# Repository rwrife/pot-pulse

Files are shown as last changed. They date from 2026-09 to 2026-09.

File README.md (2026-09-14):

# Pot Pulse

USB-powered ESP32-C3 plant-shelf monitor for home growers to track soil moisture, light, and microclimate trends in a local dashboard without cloud accounts or automatic watering.

## Motivation
Houseplant care is mostly guesswork between watering days. People often overwater because they cannot see trend data (light, moisture, humidity) across multiple pots in one place.

## Target users
- Home plant hobbyists with 1–20 potted indoor plants
- Small office/shared-space plant caretakers
- Makers who want a safe, low-voltage, locally controlled monitoring tool

## Concrete use cases
1. Compare morning/evening light exposure per shelf position.
2. Track soil moisture drop rate after watering to tune intervals.
3. Spot dry microclimates near windows/vents before plants decline.
4. Export a local history snapshot for seasonal care adjustments.

## Intended end-to-end workflow
1. Assemble device (SELV USB only) and connect sensors for each monitored pot zone.
2. Join device to local network (or direct USB setup mode).
3. Name shelves/zones in the companion app.
4. Calibrate moisture probes with dry/wet reference points.
5. Review live status + trend charts; set local reminder thresholds.
6. Export CSV/JSON snapshots for personal records.

## MVP features
- ESP32-C3 firmware with periodic sampling (moisture, light, temp/humidity)
- Local-first companion web app (mobile + desktop browsers)
- Per-zone calibration profiles and health-state bands (informational only)
- On-device ring buffer with timestamped readings
- Local network API for status/history/export
- USB recovery/provisioning flow
- Versioned backup/restore of settings and zone metadata

## Non-goals (MVP)
- Automatic watering, relays, or pumps
- Any mains-voltage control path
- Cloud account requirement or remote telemetry service
- Plant diagnosis/treatment claims
- Outdoor/weatherproof deployment

## Privacy, permissions, and data ownership
- Local-first by default: data stored on device and exported by user action.
- No required cloud service.
- Companion app only requests local-network/browser storage permissions needed for setup, caching, and export.
- User can delete local history and reset device from settings.

## Safety limits
- Prototype scope is **SELV USB power only (5V)**.
- Monitoring only; no high-power actuators.
- Not a life-safety, agricultural compliance, or medical system.

## Source tree and artifact policy
Hardware implementation is delivered as editable KiCad source files (not image-only schematics):

- `hardware/kicad/pot-pulse.kicad_pro`
- `hardware/kicad/pot-pulse.kicad_sch`
- `hardware/kicad/pot-pulse.kicad_pcb`

Final BOM source of truth will live in KiCad schematic symbol properties and be exported to tracked `bom/bom.csv`.

## Current status
- ✅ Repository scaffold and execution backlog created
- ✅ MVP architecture, interface ownership, non-goals, and risk baseline documented in [`docs/architecture.md`](docs/architecture.md)
- ✅ Datasheet-backed critical component selection documented in [`hardware/component-selection.md`](hardware/component-selection.md)
- ✅ Editable KiCad project, DRC/ERC evidence, and pad-net cross-check tooling under [`hardware/kicad/`](hardware/kicad/)
- ✅ Firmware MVP with repeatable native tests and ESP32-C3 builds under [`firmware/`](firmware/)
- ✅ Companion app MVP with repeatable typecheck/test/build under [`app/`](app/)
- ✅ Integration bring-up + assembly docs, evidence matrix, and fabrication preview bundle under [`docs/`](docs/)
- 🚧 Production-ready fabrication release still blocked by open PCB unconnected items (see `docs/evidence/2026-09-14/drc.json`)

## Milestones
1. Architecture and risk baseline
2. Datasheet-backed component selection
3. KiCad schematic and ERC
4. Schematic-source BOM and non-schematic procurement tracking
5. PCB layout and DRC
6. Firmware MVP with repeatable build/tests
7. Companion app MVP with local export
8. Integration docs and fabrication-ready release package

See [`PLAN.md`](PLAN.md) for the authoritative issue dependency graph and exit gates.

## Integration handoff docs

- Bring-up procedure: [`docs/bring-up.md`](docs/bring-up.md)
- Assembly sequence and checks: [`docs/assembly.md`](docs/assembly.md)
- Evidence classification: [`docs/evidence-matrix.md`](docs/evidence-matrix.md)
- Fabrication/release workflow: [`docs/release-artifacts.md`](docs/release-artifacts.md)
- Explicit media placeholders: [`docs/media-placeholders.md`](docs/media-placeholders.md)

## Development quickstart
### Firmware
- Toolchain: PlatformIO (ESP-IDF framework)
- Target: ESP32-C3 dev module + custom carrier pin map

### Companion app
- TypeScript + Vite + local-first PWA behavior
- Connect to device over local HTTP/WebSocket

### Hardware
- KiCad 9 project under `hardware/kicad/`
- BOM exported to `bom/bom.csv`

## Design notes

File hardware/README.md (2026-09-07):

# Hardware Overview (Scaffold)

## System block description
Pot Pulse hardware is a USB-powered sensing platform centered on an ESP32-C3 module. It connects low-voltage sensors for:
- ambient temperature/humidity,
- shelf light level,
- multiple soil-moisture channels.

A planned custom carrier provides protection, connectors, debug access, and mounting points.

## Controller choice
- **Primary controller:** Espressif `ESP32-C3-MINI-1-H4X` module (Wi‑Fi + native USB, 4 MB flash).
- Rationale: enough I/O/peripherals for multi-sensor polling and local API hosting.

The datasheet-backed selections for the first schematic pass are recorded in
[`component-selection.md`](component-selection.md), with machine-readable MPN,
supplier, availability, and lifecycle evidence in
[`component-selection.csv`](component-selection.csv). The CSV is an issue #3
handoff only; once the schematic exists, KiCad symbol properties become the BOM
source of truth.

## Interfaces
- USB-C or USB-micro for power + provisioning/debug
- I2C bus for temp/humidity + light sensors
- Analog inputs (direct or via external ADC/mux) for capacitive moisture channels
- UART/JTAG pads for debug/programming

## Power plan
- SELV **USB 5V only** input.
- Onboard 3.3V regulation for logic and sensors.
- Reverse-polarity/overcurrent protections documented in schematic milestone.

## Enclosure/assembly concept
- Small desktop/shelf enclosure with vent slots.
- Detachable sensor leads to each pot zone.
- Standard standoffs/fasteners for at-home assembly.

## Safety limits
- No mains wiring.
- No pump/relay/high-power load control in MVP.
- Indoor hobby monitoring only.

## Expected KiCad deliverables
Planned editable source files:
- `hardware/kicad/pot-pulse.kicad_pro`
- `hardware/kicad/pot-pulse.kicad_sch`
- `hardware/kicad/pot-pulse.kicad_pcb` (if custom PCB remains in scope)

Expected evidence artifacts (later milestones):
- ERC and DRC outputs
- schematic PDF
- Gerbers/drill files
- BOM export from schematic properties (`bom/bom.csv`)

Current state: critical parts selected and the issue #3 first-pass KiCad schematic is available under [`kicad/`](kicad/). Native ERC reports 0 errors and 0 warnings; PCB/layout and physical validation remain later milestones.

Validate the selection handoff from the repository root:

```sh
python3 scripts/validate_component_selection.py
```

Reproduce and validate the schematic with the commands in [`kicad/README.md`](kicad/README.md).

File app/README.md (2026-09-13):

# Pot Pulse Companion App

Local-first companion app (issue #7): setup, live status + trends, and
user-owned export/backup/restore/delete — no cloud, no accounts. Consumes the
frozen `/api/v1` contract from [`docs/protocol.md`](../docs/protocol.md) as
implemented by firmware issue #6.

## Stack (pinned)

| Component | Version |
|---|---|
| Node.js (CI + local) | 22.x |
| TypeScript | 5.6.3 |
| Vite | 5.4.11 |
| Vitest | 2.1.8 |

Vanilla DOM + TypeScript (no framework) keeps the bundle ~15 kB and the
dependency surface minimal.

## Commands

```sh
cd app
npm ci            # pinned install from package-lock.json
npm run typecheck # tsc --noEmit
npm run test      # vitest run (47 unit tests)
npm run build     # production bundle -> app/dist/
npm run dev       # dev server (point it at a device on the LAN)
```

## How it talks to the device

- `src/api/client.ts` — typed client for every frozen resource:
  status, history, pair/request, calibration, config, export, backup,
  restore, history delete (`?confirm=confirm`), reset
  (`{level:"full-firmware",confirm:"confirm"}`). Sends `X-PotPulse-Token`
  once paired; maps `401/409/422/428` to typed errors; tolerates unknown
  additive fields (protocol forward-compat rule).
- `src/core/validation.ts` — mirrors the firmware's frozen bounds client-side
  (zone name ≤ 32, interval 30 s–15 min, `dry_raw != wet_raw`,
  `0 ≤ dry < wet ≤ 1`, history limit 1–500, `backup_version == 1`).
  The device always re-validates.

## Data ownership

- Device flash is authoritative; browser storage (`src/core/store.ts`) holds
  ONLY the device address, pairing token, and a presentation hint — never
  readings. Corrupt cache falls back to defaults.
- Export (CSV/JSON) and backup download happen only on explicit user action;
  the restore file is parsed + validated before posting, and the device
  applies it atomically-or-not-at-all.
- Two separate destructive controls: **Delete device history** (requires the
  frozen confirmation word; settings/calibration kept) and **Delete local app
  data** (wipes this browser's cache only).

## Accessibility basics (issue #7 AC 4)

- Landmarks + skip link; tablist with `aria-selected` and labelled panels.
- `role="status" aria-live="polite"` announcement line for every action result.
- Every input has a real `<label>`; token field is `type="password"`.
- ≥44 px touch targets, visible focus outlines, dark-mode tokens,
  `clamp()`/rem text that scales, WCAG-AA-matched palette, trend chart has a
  text `aria-label`, destructive actions confirm before firing.

## Evidence boundary (issue #7)

- **Static / automated:** `tsc --noEmit` clean; 47 vitest unit tests against a
  scripted fake of the frozen protocol (auth fail-closed, 409 pairing, 428
  confirmation, CSV escaping, uncalibrated-never-valid rendering);
  production Vite build; GitHub Actions `app` workflow.
- **Not claimed:** no end-to-end run against physical ESP32-C3 hardware and
  no screen-reader manual audit — both are bench/field work owned by issue #8.

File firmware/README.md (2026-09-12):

# Firmware (Pot Pulse sensor node)

ESP32-C3 firmware MVP for the pot-pulse carrier (issue #5 board). Local-first:
HTTP JSON API on the LAN plus USB-serial provisioning/recovery; no cloud.

## Layout

- `src/pp/` — portable core (C++17, no Arduino includes): sensor drivers,
  calibration, bounded history, config/pairing store, JSON renderers.
  Compiled in both targets and unit-tested natively.
- `src/main.cpp` — ESP32 device layer: pin map, WebServer endpoints, USB
  serial console, flash persistence (Preferences + LittleFS).
- `test/test_core/` — Unity tests (native env) with fake I2C/clock/KV HALs.

## Toolchain (pinned, AC 1)

| Component | Version |
|---|---|
| PlatformIO Core | 6.1.18 |
| platform-espressif32 | 6.10.0 |
| Arduino core (framework-arduinoespressif32) | 2.0.17 |
| ArduinoJson | 7.4.2 |
| Unity | 2.6.1 |
| Host compiler | g++ `-std=gnu++17` |

Pins live in `platformio.ini` (`espressif32@6.10.0`, `native@1.2.1`,
`ArduinoJson@7.4.2`). Any bump must re-run both commands below and refresh
this file.

## Repeatable build/test commands

```sh
cd firmware
pio test -e native      # portable-core unit tests (19 cases)
pio run  -e esp32c3     # device firmware binary (ESP32-C3)
```

Verified on 2026-09-12 (issue #6 implementing PR):
- `pio test -e native` → `19 test cases: 19 succeeded`
- `pio run -e esp32c3` → `SUCCESS`, RAM 12.2% (40,100/327,680 B),
  Flash 68.0% (891,772/1,310,720 B)

## Flashing (bench, once hardware is available)

```sh
pio run -t upload --upload-port /dev/ttyACM0
pio device monitor
```

## USB serial console (IF-DBG-01 — recovery without Wi-Fi/cloud)

Native USB CDC at 115200. Commands:
`status` · `pair list` · `pair confirm <pair_id>` · `wifi <ssid> <pass>` ·
`reset wifi` · `reset full-firmware` · `help`

Pairing: the app POSTs `/api/v1/pair/request`, then the user runs
`pair confirm <pair_id>` on this console; the 128-bit token is printed ONLY
on the local serial console (out-of-band confirmation, architecture §7).

## Reset levels (protocol `POST /api/v1/reset`)

- `full-firmware` (requires `confirm:"confirm"` + pairing): erases pairing
  tokens, settings, zone metadata, calibration, retained history. Wi-Fi
  credentials are RETAINED so the device stays reachable on the LAN.
- Serial `reset wifi` erases only network credentials.
- A `factory` level erasing Wi-Fi too is deferred until a bench procedure
  exists (needs physical access anyway).

## Evidence boundary (issue #6)

- **Static / automated:** datasheet-transcribed drivers with citations
  (SHT4x DS v6.4, VEML7700 Rev 1.8 + AN 84323, ADS1115 2024 datasheet);
  19 native unit tests; successful ESP32-C3 compile+link.
- **Not claimed:** no bench run on real silicon/sensors, no RF/network
  integration test, no EMC/thermal/field evidence. End-to-end pairing +
  API behavior on hardware is bench work owned by issue #8.
- The HTTP request-handling paths (WebServer glue) are compile-verified only;
  their JSON payloads and state machines ARE unit-tested at the core level.

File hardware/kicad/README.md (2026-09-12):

# Pot Pulse KiCad project

This directory contains the editable KiCad 9 project for the USB-powered Pot Pulse four-zone sensor node: first-pass schematic (issue #3) and first-pass PCB (issue #5).

## Files

- `pot-pulse.kicad_pro` — KiCad project settings.
- `pot-pulse.kicad_sch` — editable schematic source of truth.
- `pot-pulse.kicad_pcb` — editable first-pass PCB (generated by `build_pcb.py`, routed via FreeRouter, DRC-adjudicated).
- `lib/pot-pulse.kicad_sym` — project symbols whose pin maps were transcribed from the manufacturer documents cited in `../component-selection.md`.
- `lib/pot-pulse.pretty/` — project land patterns (ESP32-C3-MINI-1, VEML7700) transcribed from the datasheets cited in `../component-selection.md`; generated by `generate_footprints.py`.
- `fp-lib-table` / `sym-lib-table` — project library registration so the board opens on any machine with KiCad 9.
- `generate_schematic.py` — reproducible first-capture generator; the generated schematic remains editable in KiCad.
- `validate_schematic.py` — static acceptance checks for required parts, properties, nets, pin mappings, test access, and the native ERC summary.
- `netlist_to_json.py` — exports `reports/pcb-input/{netlist,components}.json` (placement/routing input data derived from the schematic netlist).
- `build_pcb.py` — generates `pot-pulse.kicad_pcb` through the pcbnew API (outline, placement table with courtyard/edge asserts, net classes, RF rule areas, pours, text).
- `generate_footprints.py` — generates the project land patterns from datasheet dimensions.
- `route_driver.py` — Specctra DSN export / SES import driver (import saves immediately before probing).
- `dsn_strip_inner_layers.py` — keeps the autorouter on F.Cu/B.Cu so the inner planes stay solid.
- `rip_up_dangling.py` / `rip_up_zone.py` / `rip_up_congested.py` — stranded-fragment and surgical rip-up helpers between router passes.
- `close_stubs.py` — deterministic final stub closer (collision-capsule tested; `--dry` reports LEFT pairs verbatim).
- `fill_zones.py` — headless "Fill All Zones".
- `silk_hygiene.py` — post-route silkscreen cleanup (hides dense-passive refs, shrinks TP/test refs, enforces 0.15 mm text stroke).
- `reload_probe.py` / `check_placement_vs_table.py` / `board_inventory.py` / `list_plane_tracks.py` / `lane_blockers.py` — verification probes (reload integrity, placement-vs-table drift, copper inventory, residual-gap diagnosis).
- `reports/erc.rpt` — native KiCad 9 electrical-rules report.
- `reports/schematic-analysis.txt` — supplemental static analyzer output.
- `reports/pot-pulse.net` — netlist export feeding `netlist_to_json.py`.
- `reports/drc-placement.json` — placement-stage native DRC (pre-routing).
- `reports/routing/` — per-pass DSN/SES/DRC evidence; each `passN-drc.json` is the `kicad-cli` truth for that pass.
- `reports/drc-final.json` — committed final DRC state for `pot-pulse.kicad_pcb`.

Layout intent, keepout strategy, grounding approach, assembly/testability notes, and documented first-pass gaps: `../pcb-design-notes.md`.

## Reproduce and verify

The host needs KiCad 9 symbol libraries and Python 3.11+:

```sh
python3 -m venv /tmp/pot-pulse-kicad-venv
/tmp/pot-pulse-kicad-venv/bin/pip install -r hardware/kicad/requirements.txt
KICAD_SYMBOL_DIR=/usr/share/kicad/symbols \
  /tmp/pot-pulse-kicad-venv/bin/python hardware/kicad/generate_schematic.py
kicad-cli sch erc -o hardware/kicad/reports/erc.rpt hardware/kicad/pot-pulse.kicad_sch
KICAD_SYMBOL_DIR=/usr/share/kicad/symbols \
  /tmp/pot-pulse-kicad-venv/bin/python hardware/kicad/validate_schematic.py \
  --erc hardware/kicad/reports/erc.rpt
```

The PCB steps need the `pcbnew` Python bindings (KiCad container image); all
scripts run inside `hardware/kicad/`:

```sh
kicad-cli sch export netlist pot-pulse.kicad_sch -o reports/pot-pulse.net
python3 netlist_to_json.py
python3 build_pcb.py                       # asserts courtyard/edge placement
python3 reload_probe.py                    # reload integrity + pad-net probe
python3 check_placement_vs_table.py        # board vs build_pcb.py table
python3 route_driver.py export reports/routing/passN.dsn
# host: java -Djava.awt.headless=true -jar freerouting-2.4.1.jar \
#   -de passN-2l.dsn -do passN.ses -mp 12 -gui.enabled=false   (after dsn_strip_inner_layers.py)
python3 route_driver.py import reports/routing/passN.ses
python3 rip_up_dangling.py && python3 fill_zones.py && python3 silk_hygiene.py
python3 close_stubs.py --drc reports/routing/passN-drc.json    # deterministic final stubs
kicad-cli pcb drc --severity-error --severity-warning --format json \
  --output reports/drc-final.json pot-pulse.kicad_pcb
```

The repository's headless `kicad-cli` wrapper runs KiCad 9 in a container. Committed reports are generated from the editable sources, not hand-authored.

## Evidence boundary

Schematic files provide **static schematic and native ERC evidence**. The PCB
provides **static layout + native DRC evidence plus autorouter-derived routing
provenance**. These files do not provide simulation, assembled-board, EMC,
environmental, field, or calibration evidence. RF keepout geometry is
datasheet-derived; measured RF performance is bench evidence not yet claimed.
USB full-speed impedance is not yet stackup-verified (documented gap in
`../pcb-design-notes.md`).

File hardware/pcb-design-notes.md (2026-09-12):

# Pot Pulse first-pass PCB design notes

Editable source: [`kicad/pot-pulse.kicad_pcb`](kicad/pot-pulse.kicad_pcb)
(project [`kicad/pot-pulse.kicad_pro`](kicad/pot-pulse.kicad_pro), KiCad 9).
The board is generated reproducibly through the `pcbnew` Python API —
see `kicad/build_pcb.py` for the placement table and `kicad/README.md` for
the reproduce commands. This document records the layout intent and the
evidence boundaries for issue #5.

## Board outline and mounting strategy

- **Outline:** 70 × 50 mm rectangle on `Edge.Cuts`, 0.05 mm line width.
- **Mounting:** three M3 clearance holes (3.2 mm drill, `MountingHole_3.2mm_M3`
  footprints MK1/MK2/MK3) at (3.6, 3.6), (3.6, 46.4), (63.5, 3.6). The
  top-right corner is intentionally empty: the JST zone-connector bank
  (J2–J5) owns that edge, and `hardware/requirements.md` requires "at least
  two mounting holes." Three holes at non-collinear corners keep the board
  flat in a standoffs enclosure. Hole-to-courtyard clearance is enforced by
  `build_pcb.py check_placement()` and re-checked by native DRC.
- **Layers:** 4-layer intent — F.Cu signal / In1.Cu solid GND plane /
  In2.Cu +3V3 plane / B.Cu signal, 1.6 mm FR-4. If the fab quote pushes
  toward 2 layers, signal routing is already complete on F.Cu/B.Cu only
  (the autorouter was constrained to those layers) and the inner planes
  can be dropped by removing the pour zones; signal integrity then relies
  on the bottom-side return path.

## Connector placement

- **J1 USB-C (power + provisioning):** left edge, mouth centered at
  y = 25 mm, mating face flush with the edge — the cable exits left and
  never crosses the sensor-cable bundle.
- **J2–J5 JST-PH zone connectors:** right edge at x = 66.9 mm, 9.2 mm
  pitch, cables exit rightward away from the antenna band.
- **J6 6-pin debug/programming header:** top edge (55, 47.5), rotated 180°
  so the keyed notch faces outward; sits next to the MCU for short UART/BOOT
  fanout.
- **Sensor/RF separation:** USB entry + input protection + buck sit on the
  top band between J1 and the MCU; the ADS1115 + probe conditioning + zone
  bank live on the right; the ESP32-C3-MINI-1 is rotated 180° so its PCB
  antenna points at the bottom edge.

## Keepout strategy

- **RF keepout (hard rule area, all copper/via/track forbidden):** rectangle
  x 24–46 mm, y < 17.4 mm in front of the U2 antenna end (bottom edge). It
  stops 0.075 mm clear of U2's courtyard so the rule area does not graze the
  module (a grazing rule area flags the footprint as an `items_not_allowed`
  DRC error). This matches the ESP32-C3-MINI-1 datasheet keepout figure;
  actual RF performance still requires bench verification.
- **Edge strategy:** copper edge clearance 0.5 mm design rule; test points
  and mounting holes are placed so no silk or copper violates it.
- The keepouts are committed in the board file as rule-area zones (KiCad
  "rule areas"), so they are DRC-enforced, not just documentation.

## Grounding approach

- **Solid GND plane:** In1.Cu is a single uninterrupted +GND pour with no
  splits; F.Cu carries a second GND pour stitched to the plane through via
  fences along the main signal corridors and under every IC ground pad.
  This is the "explicit grounding approach" for the critical nets: USB
  shield/return, buck input/output loops, and ADC analog returns all have a
  plane directly beneath their signal layer.
- **+3V3:** In2.Cu plane plus an F.Cu pour around the sensor/ADC cluster;
  the Power net class (0.5 mm / 0.7–0.35 vias) carries VBUS → protection →
  buck → +3V3 bulk path.
- **Analog class:** MOISTURE_AIN* / PROBE*_RAW run 0.20 mm / 0.25 mm
  clearance away from the buck switch node and the antenna band; returns
  reference the solid GND plane.

## Critical-net routing record (first pass)

| Net group | Class | Notes |
|---|---|---|
| VBUS, +5V_PROTECTED, SW_NODE, +3V3, GND | Power 0.5 mm | Short buck loop J1→F1/D1→U1→L1→C3/C4; bulk caps adjacent to the IC. |
| USB_DP/DM, USB_CONN_DP/DM | USB 0.15 mm | USB-C staggered 0.5 mm-pitch pads (0.3×1.15 mm) physically cannot pass a 0.2 mm corridor; 0.15 mm is the documented fanout compromise. **Not impedance-controlled on this pass** — see gaps below. |
| I2C (SCL/SDA) | Default 0.2 mm | Shared bus U2→R4/R5 pull-ups→U5/U6→TP5/TP6, single trunk, no stubs >10 mm. |
| MOISTURE_AIN* / PROBE*_RAW | Analog | Filtered (R/C grid) per probe channel to U3 (ESD) and U4 (ADS1115). |
| EN, BOOT, U0RXD/TXD, REG_PG, ADC_ALERT_N | Default | Debug/diagnostic nets to J6 and test points. |

## DRC evidence and remaining known gaps

Native reports (regenerate with the commands in `kicad/README.md` §PCB):

- `kicad/reports/drc-placement.json` — placement-only stage (before routing).
- `kicad/reports/routing/passN-drc.json` — per-router-pass adjudication.
- `kicad/reports/drc-final.json` — final committed state.

Adjudication is always `kicad-cli pcb drc --format json` on the reloaded
board, never the router's own log (the two metrics count different things).

Committed final state (`reports/drc-final.json`): **0 error-class violations
(clearance/shorts/courtyards/keepouts/copper-edge all clean) and 0 warning-
class violations except one dangling via; 5 ratsnest pairs remain unrouted**:

| # | Net | Gap (verbatim DRC pair) |
|---|-----|---|
| 1 | +3V3 | `Pad 3 [/+3V3] of U5` ↔ 1.77 mm F.Cu stub |
| 2 | I2C_SCL | `Pad 2 [/I2C_SCL] of U5` ↔ 3.21 mm F.Cu stub |
| 3 | I2C_SDA | dangling B.Cu via at (52.97, 24.94) ↔ `Pad 1 [/I2C_SDA] of U5` |
| 4 | USB_CONN_DM | `Pad A7 [/USB_CONN_DM] of J1` ↔ 0.88 mm F.Cu stub |
| 5 | VBUS | `Track [/VBUS] on B.Cu` (4.80 mm) ↔ `Track [/VBUS] on B.Cu` |

Root causes are congestion, not missing routes:

- **U5 (SHT4x DFN-4, 0.8 mm pitch, 0.5×0.3 mm pads):** at the 0.2 mm
  design clearance a track physically cannot pass between adjacent pads
  (pad gap 0.5 mm < track+2×clearance = 0.6 mm). The three U5 fanout stubs
  need either a local clearance relaxation (like the USB class) or a small
  pad sweep before the next router pass. Documented as a known limitation
  for pass 2, not hidden.
- **USB-C staggered fanout (USB_CONN_DM A7):** the 0.5 mm staggered row is
  already routed at the 0.15 mm USB-class compromise; the last A7 hop
  collides with the DP stub. Needs a fan-out re-order (B-row first) next pass.
- **VBUS B.Cu gap:** the A9↔A4 bridge is closed (deterministic stub-closer);
  the remaining 4.8 mm gap is between two B.Cu trunks across the USB corner,
  blocked by J1 pads/shield. A Z-detour at 0.2 mm clearance fails the
  capsule collision test (dumped verbatim by `lane_blockers.py`).

`close_stubs.py --dry` against the final DRC reports these pairs verbatim
(`LEFT` lines); `final_pipeline.py` reproduces the exact committed board from
`build_pcb.py` + `reports/routing/t1.ses`.

Documented first-pass gaps (intentional, each with a rationale):

1. **USB full-speed impedance is not controlled** on the 4-layer stackup
   guess (no fab stackup confirmed yet). Acceptable for full-speed USB
   provisioning per the architecture doc; revisit when a fab stackup is
   quoted.
2. **No solder-mask/paste design review against a specific fab** — design
   rules are set to JLCPCB-2-layer-capable minimums (0.2 mm clearance,
   0.2 mm track, 0.3/0.6 vias); fab-specific CAM review is a fabrication
   milestone, not this issue.
3. RF keepout geometry is datasheet-derived; measured antenna performance
   is bench evidence we do not yet claim.

## Assembly and testability notes

- **Probe access:** sixteen 1.5 mm test points (TP1–TP16) in two blocks
  (bottom-left rail/debug cluster: VBUS, +5V_PROTECTED, +3V3, GND, I2C,
  USB_DP/DM, AIN2/AIN3; bottom-right analog/diagnostic row: REG_PG, EN,
  BOOT, ADC_ALERT_N, AIN0/AIN1). All are outside the RF keepout and clear of
  connector mating envelopes. TP references stay visible on silk (identity
  is part of testability); dense passives use F.Fab-only references.
- **Connector orientation checks (assembly-time):** J1 mouth must be flush
  with the left Edge.Cuts line (0.2 mm inset); J2–J5 locking-latch side
  faces the board edge so cables pull outward; J6 notch faces outward for
  ribbon-key alignment. Silkscreen pin-1 marks are present on J2–J6; J1 is
  mechanically keyed.
- **Polarity/orientation-sensitive parts:** D1 (SOD-523) band toward the
  buck input; U7 USBLC6 pin-1 dot toward J1; U1 buck EP with thermal via
  cluster (do not hand-solder without hot-air); F1 fuse 1812; C1/C3/C4
  1206 bulk — all have silk pin-1/orientation marks from footprint graphics.
- **Mounting:** M3 standoffs at MK1–MK3; no components within the 6 mm
  courtyard of any hole.
- **Test sequence hook:** TP1/TP2/TP3/TP4 are 5V/3V3/GND rails — first
  bring-up step is a rail check at these four pads before plugging in the
  zone cables.

## Reproducing the routing evidence

```sh
# from hardware/kicad/ (pcbnew container per kicad/README.md)
python3 netlist_to_json.py            # refresh reports/pcb-input/*.json
python3 build_pcb.py                  # rebuild board from placement table
python3 route_driver.py export reports/routing/passN.dsn
# host: FreeRouter headless (JDK25 + freerouting-2.4.1.jar)
#   java -Djava.awt.headless=true -jar freerouting-2.4.1.jar \
#     -de passN.dsn -do passN.ses -mp 12 -gui.enabled=false
python3 route_driver.py import reports/routing/passN.ses
python3 rip_up_dangling.py            # drop stranded fragments
python3 fill_zones.py                 # refill pours after import
python3 close_stubs.py --drc reports/routing/passN-drc.json   # deterministic final stubs
kicad-cli pcb drc --severity-error --severity-warning --format json \
  --output reports/drc-final.json pot-pulse.kicad_pcb
```

`dsn_strip_inner_layers.py` keeps the router on F.Cu/B.Cu so the inner
planes stay solid; `rip_up_congested.py` is the surgical rip-up used to
clear autorouter dead-ends before a targeted pass.

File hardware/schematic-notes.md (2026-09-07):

# Schematic notes and interface contract

**Revision:** A0 first-pass schematic, 2026-09-07
**Editable source:** [`kicad/pot-pulse.kicad_sch`](kicad/pot-pulse.kicad_sch)

The schematic implements the issue #1 architecture and issue #2 datasheet-backed selections. Manufacturer documents listed in [`component-selection.md`](component-selection.md) are the electrical ground truth. KiCad connectivity and ERC are static evidence, not physical validation.

## Power tree

```text
USB-C J1 VBUS
  -> F1 MF-MSMF050-2 (0.50 A hold / 1.00 A trip)
  -> +5V_PROTECTED
     -> D1 ESD5Z5.0T1G to GND
     -> U1 TPS62162DSGR fixed 3.3 V buck
        -> L1 2.2 uH
        -> +3V3
```

`+3V3` powers the ESP32-C3 module, ADS1115, SHT40, VEML7700, probe connectors, and I2C pull-ups. `VBUS`, `+5V_PROTECTED`, `+3V3`, and `GND` have ERC source declarations and labeled test pads. The 0.50 A PPTC rating and regulator capacity are static ratings only; startup, radio burst droop, ripple, and nuisance-trip behavior remain bench work for issue #8.

TPS62162 connections follow TI's fixed-output guidance: FB and the exposed pad go to GND, VOS senses `+3V3`, SW feeds the selected 2.2 uH inductor, and PG has a 100 kOhm pull-up. The input/output network is 10 uF plus 100 nF at the input and 22 uF at the output.

## Named interfaces

| Interface | Nets | Ownership / use |
|---|---|---|
| USB Type-C sink | `VBUS`, `CC1`, `CC2`, `USB_CONN_DP`, `USB_CONN_DM` | J1 entry; CC1/CC2 each have independent 5.1 kOhm Rd |
| Protected native USB | `USB_DP`, `USB_DM` | U7 USBLC6-2SC6 to ESP32-C3 GPIO19/GPIO18 |
| Regulator status | `REG_PG`, `SW_NODE` | `REG_PG` is testable; `SW_NODE` is local to the buck/inductor loop |
| Shared I2C | `I2C_SDA`, `I2C_SCL` | ESP32 GPIO4/GPIO5; ADS1115 0x48, SHT40 0x44, VEML7700 0x10 |
| ADC ready | `ADC_ALERT_N` | ADS1115 open-drain ALERT/RDY to ESP32 GPIO6 with 10 kOhm pull-up |
| Probe entry | `PROBE1_RAW` ... `PROBE4_RAW` | JST PH pin 3 through TPD4E05U06 boundary protection |
| Filtered moisture | `MOISTURE_AIN0` ... `MOISTURE_AIN3` | 1 kOhm / 100 nF RC outputs to ADS1115 AIN0..AIN3 |
| Reset / boot | `EN`, `BOOT_GPIO9` | EN pull-up/1 uF reset delay; GPIO9 boot strap pull-up and debug access |
| UART fallback | `U0RXD`, `U0TXD` | ESP32-C3 GPIO20/GPIO21 at J6 |

## Connector pinout

### J2–J5 moisture probes

All four connectors use the same orientation:

1. `+3V3`
2. `GND`
3. `PROBEn_RAW`

They target JST `S3B-PH-K-S(LF)(SN)` and the SEN0193 PH2.0-3P cable family. The board silkscreen and assembly guide must repeat this mapping, and issue #5/#8 must check the received cable orientation before power is applied.

### J6 unpopulated debug/program pads

1. `+3V3`
2. `GND`
3. `EN`
4. `BOOT_GPIO9`
5. `U0RXD`
6. `U0TXD`

Native USB is the normal provisioning/recovery path. J6 is a fallback for UART flashing and controlled reset/boot entry.

## Test access

The schematic provides 16 unpopulated test pads:

- rails: `VBUS`, `+5V_PROTECTED`, `+3V3`, `GND`;
- representative bus: `I2C_SDA`, `I2C_SCL`;
- USB: `USB_DP`, `USB_DM`;
- control/status: `REG_PG`, `EN`, `BOOT_GPIO9`, `ADC_ALERT_N`;
- analog: `MOISTURE_AIN0` through `MOISTURE_AIN3`.

Issue #5 owns final probe-pad placement, keepouts, silkscreen labels, and physical accessibility.

## Net naming conventions

- `+<voltage>` denotes a regulated or protected power rail, for example `+3V3` and `+5V_PROTECTED`.
- `VBUS` is the raw USB connector rail before F1.
- `_N` suffix means active-low or open-drain asserted-low behavior.
- `USB_CONN_*` names the connector side of U7; `USB_*` names the protected MCU side.
- `PROBEn_RAW` names an external connector node before the RC filter.
- `MOISTURE_AINn` names a filtered ADS1115 single-ended channel.
- `I2C_*` is the single shared assembled bus; only R4/R5 provide board pull-ups.
- `SW_NODE` is a high-dV/dt local switching node and must not be used elsewhere.
- GPIO function is included where it is an interface contract (`BOOT_GPIO9`, `U0RXD`, `U0TXD`); spare GPIO nets are explicitly named and testable in the source but are not external interfaces.

## Datasheet pin-map checks

The project symbol library records these reviewed mappings:

- ESP32-C3-MINI-1 v2.2 Table 3-1: pad 3=3V3, 8=EN, 18=GPIO4, 19=GPIO5, 20=GPIO6, 23=GPIO9, 26=USB_D-, 27=USB_D+, 30=GPIO20/U0RXD, 31=GPIO21/U0TXD, and all documented GND/NC pads.
- ADS1115 Rev. E Table 4-1: 1=ADDR, 2=ALERT/RDY, 3=GND, 4..7=AIN0..AIN3, 8=VDD, 9=SDA, 10=SCL.
- TPS6216x Rev. E pin functions: 1=PGND, 2=VIN, 3=EN, 4=AGND, 5=FB, 6=VOS, 7=SW, 8=PG, exposed pad=AGND.
- SHT4x v7.3 Figure 18: 1=SDA, 2=SCL, 3=VDD, 4=VSS.
- VEML7700 Rev. 1.8: 1=SCL, 2=VDD, 3=GND, 4=SDA.
- TPD4E05U06 Rev. O Table 4-2: protected channels on 1, 2, 4, 5; GND on 3 and 8; remaining pads NC.

## ERC configuration and intentional limits

The committed native KiCad report must contain zero electrical errors and zero warnings. No electrical violation is waived. Two footprint identifiers (`pot-pulse:ESP32-C3-MINI-1` and `pot-pulse:VEML7700`) intentionally name project land patterns that issue #5 must implement and validate against the manufacturer drawings before PCB placement. That is a PCB/library handoff, not electrical ERC evidence.

## Evidence not yet available

- No PCB layout or DRC evidence exists (issue #5).
- No SPICE simulation was run; this milestone does not claim ripple, transient, filter-settling, or signal-integrity simulation.
- No assembled hardware, voltage/current measurement, USB enumeration, sensor readout, ESD, thermal, environmental, or field test was performed.
- Probe calibration accuracy and dry/wet repeatability remain firmware/bench tasks.

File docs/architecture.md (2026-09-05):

# Pot Pulse MVP Architecture and Risk Baseline

**Status:** Proposed baseline; becomes the accepted MVP baseline when issue #1 is merged.

**Scope:** Issues #2–#8 must conform to this document or update it explicitly in the same pull request.

**Evidence boundary:** This document defines design intent. It is not electrical, simulation, bench, field, or certification evidence.

## 1. Purpose and constraints

Pot Pulse is a local-first, indoor plant-monitoring system. One USB-powered sensor node samples four soil-moisture zones plus device-level illuminance, temperature, and relative humidity. Firmware calibrates and stores readings, then exposes a versioned local API. A browser-based companion app owns setup, visualization, user-initiated export, and local backup/restore workflows.

The MVP is constrained to:

- SELV USB 5 V input and 3.3 V logic/sensors;
- at least four independent capacitive moisture channels;
- one device-level digital ambient sensor and one digital light sensor;
- local operation without a cloud account or cloud relay;
- a normal-mode average-current target of 250 mA or less;
- indoor operation at a nominal 10–35 °C ambient;
- a user-serviceable sensor-node assembly with a target carrier size of 120 mm × 80 mm or less and at least two mounting holes;
- a prototype electronics-plus-enclosure cost target of USD 35–60 and a soft ceiling of USD 75, excluding the host device, tools, shipping, and tax.

This architecture is authoritative for subsystem boundaries, ownership, safety constraints, and non-goals. [`hardware/requirements.md`](../hardware/requirements.md) remains authoritative for measurable hardware acceptance requirements. Any conflict must be resolved by updating both documents in the same pull request; neither silently overrides the other.

Exact components, packages, connector families, and the ADC/multiplexer topology are intentionally deferred to datasheet-backed component selection in issue #2. Those choices may refine this baseline but must preserve its external boundaries and requirements unless the architecture is revised explicitly.

## 2. System context

### 2.1 Context diagram

```text
                              user-owned local environment

  Capacitive probes (×4) ─┐
  Ambient sensor ─────────┼──> [ Pot Pulse sensor node ] <── USB 5 V + setup host
  Light sensor ───────────┘        |        |
                                   |        +── USB serial diagnostics/recovery
                                   |
                                   +── local HTTP / optional WebSocket
                                                |
                                                v
                                      [ Companion web app ]
                                         |             |
                                         v             v
                                  browser cache   CSV/JSON or
                                                  backup files
```

### 2.2 Block narrative

1. **Hardware platform:** accepts only SELV USB 5 V, protects and regulates the supply, connects the ESP32-C3 module to four moisture inputs and shared digital environmental sensors, and exposes programming/debug/test access.
2. **Firmware:** owns hardware initialization, scheduled sampling, quality flags, calibration transforms, bounded on-device history, configuration persistence, pairing authorization, and the versioned device API.
3. **Companion app:** discovers or connects to one device, guides naming and calibration, presents current/history data, manages user-entered metadata and reminders, and performs explicit export, backup, restore, and delete operations through documented APIs.
4. **User-controlled storage:** device flash is authoritative for device configuration, calibration, and bounded readings. Browser storage is a disposable app cache. User-created CSV/JSON and backup files are portable records controlled by the user.
5. **External systems:** the local network and USB host provide transport only. No cloud service is required for setup, normal monitoring, history, or export.

### 2.3 Trust and ownership boundaries

- The **sensor node** is the authority for raw readings, calibration parameters applied to those readings, sensor-health state, sampling cadence, and retained device history.
- The **app** is the authority for presentation state and browser-local cache. It must not silently reinterpret raw values or manufacture missing samples.
- The **user** owns exported data, plant/zone naming, reminder thresholds, and destructive-operation confirmation.
- The **local network is not assumed private enough for configuration writes**. Firmware must require a locally established pairing credential for state-changing API operations. Final authentication mechanics are a firmware/protocol decision, but unauthenticated writes are prohibited.
- Hardware provides electrical connectivity; firmware owns bus transactions. App code must not depend on pin numbers, I2C addresses, ADC channels, or component choices.

## 3. Subsystem responsibilities

### 3.1 Hardware

Hardware owns:

- USB input protection and 5 V-to-3.3 V power integrity;
- ESP32-C3 module, sensor, probe, debug, and test-point connectivity;
- signal conditioning and protection required by selected probes and external connectors;
- four electrically distinct moisture acquisition channels;
- I2C electrical implementation for the ambient and light sensors;
- connector keying/orientation documentation and enclosure mounting constraints.

Hardware does not own calibration policy, threshold meaning, retention policy, UI behavior, or network authorization.

### 3.2 Firmware

Firmware owns:

- deterministic sensor initialization and sample scheduling;
- conversion of hardware observations to typed readings with quality flags;
- dry/wet calibration storage and application per moisture zone;
- timestamps and bounded history retention;
- configuration validation, persistence, reset, and recovery;
- pairing credentials and authorization of state-changing operations;
- the `/api/v1` HTTP contract and optional WebSocket event stream;
- USB serial diagnostics and a recovery path that does not require Wi-Fi or cloud access.

Firmware must preserve raw moisture readings alongside calibrated values so calibration can be audited or replaced.

### 3.3 Companion app

The app owns:

- connection/setup guidance, zone naming, and calibration workflow;
- accessible live status and historical trend presentation;
- local reminder configuration without control of physical actuators;
- explicit CSV/JSON export, backup, restore, and deletion UX; firmware generates and validates canonical device data while the app owns user initiation, transfer, and local file handling;
- validation of user input before sending it to the device;
- clearly distinguishing offline/stale data from current device readings.

The app must consume the versioned protocol and must not directly encode board pinout or sensor-driver assumptions.

## 4. Interface contracts

| ID | Boundary | Producer / owner | Consumer | Inputs | Outputs / contract | Required verification |
|---|---|---|---|---|---|---|
| IF-PWR-01 | USB source → hardware | Hardware | Entire sensor node | SELV USB 5 V only | Protected input and regulated 3.3 V rail; normal-mode average target ≤250 mA | Schematic/ERC review; regulator/protection datasheet checks; bench rail and current measurements |
| IF-MOI-01 | Moisture probes → acquisition hardware | Hardware | Firmware sensor abstraction | Four independent analog probe signals and connector return/reference | Stable per-channel ADC observations plus open/out-of-range detectability where supported | Schematic pinout review; channel-isolation test; dry/wet bench characterization |
| IF-I2C-01 | Ambient/light sensors ↔ MCU | Hardware owns electrical bus; firmware owns transactions | Firmware drivers | 3.3 V I2C, selected addresses, interrupt lines only if documented | Typed temperature °C, relative humidity %RH, illuminance lux, and quality state | Datasheet pin/address validation; bus enumeration and fault-injection tests |
| IF-DBG-01 | USB/debug host ↔ node | Firmware owns command semantics; hardware owns physical path | Setup/diagnostic operator | USB serial or selected native USB path | Provisioning, diagnostics, and recovery/reset without cloud dependency | Repeatable flashing/recovery procedure and failed-Wi-Fi recovery test |
| IF-STO-01 | Firmware services ↔ device flash | Firmware | Firmware API/sampling services | Versioned settings, calibration, zone metadata, bounded readings | Atomic validated records; recoverable defaults after corrupt/incompatible data | Unit tests for migration, bounds, interrupted write, reset, and retention |
| IF-API-01 | Device ↔ companion app | Firmware owns `/api/v1`; app owns client use | Companion app | Pairing credential for writes; bounded query parameters | JSON status/history/config/calibration/export/backup/restore/delete/reset resources defined in [`docs/protocol.md`](protocol.md) | Shared schema/fixture tests plus local integration tests |
| IF-LIVE-01 | Device → companion app | Firmware | Companion app | Optional authenticated WebSocket subscription | Best-effort live events using the same reading schema as HTTP; HTTP remains functional fallback | Disconnect/reconnect, duplicate-event, stale-state, and polling-fallback tests |
| IF-FILE-01 | Companion app ↔ user files | Companion app | User and later app restore flow | Explicit user export/backup/restore action | Versioned UTF-8 CSV/JSON exports and validated backup files; no silent upload | Round-trip tests, malformed-file rejection, accessibility review, explicit-consent UX test |

Interface payload details belong in `docs/protocol.md`. When implementation begins, protocol changes that affect multiple subsystems require coordinated firmware fixtures and app tests in the same change or explicitly sequenced dependent changes.

## 5. End-to-end data flow

1. Firmware wakes or reaches the configured interval (30 seconds to 15 minutes) and requests one sample from each enabled sensor channel.
2. Drivers return a raw value or a typed failure. Firmware records a quality state; it does not replace a failed sample with a plausible number.
3. Firmware applies the stored per-zone dry/wet calibration to moisture observations while retaining the raw observation. Light and ambient values remain in their documented physical units.
4. Firmware assigns a timestamp and appends the sample to a bounded on-device ring buffer according to the active retention policy.
5. `GET /api/v1/status` returns the latest readings and health. Bounded history requests return retained records without exposing unrelated configuration secrets.
6. The app renders live and historical data, labels stale/offline values, and may cache responses for responsiveness. The cache is not a second source of truth.
7. Configuration, calibration, reset, delete, restore, and other writes require a pairing credential plus server-side validation. Destructive operations require explicit user confirmation.
8. Export or backup occurs only after a user action. The resulting file remains local unless the user independently moves or shares it.

### Time behavior

The MVP does not require a battery-backed real-time clock. Firmware must distinguish time that is synchronized from time that is only monotonic/relative. The protocol must expose enough status for the app to label unsynchronized samples rather than presenting them as exact wall-clock observations. The concrete synchronization mechanism is owned by firmware issue #6.

## 6. Failure and recovery behavior

- A missing or invalid sensor produces `sensor_error`/`unknown` quality, not a fabricated normal value.
- Missing calibration produces `uncalibrated`; it must not be displayed as a validated dry/ok/wet assessment.
- Loss of Wi-Fi does not stop sampling or bounded local retention.
- Loss of the optional WebSocket stream falls back to bounded HTTP polling.
- Corrupt or incompatible persisted configuration fails to validated defaults while preserving a documented recovery/reset path.
- USB recovery remains available when network onboarding fails.
- Storage pressure is handled by the documented bounded-retention policy; history must not grow without limit.
- The app marks cached readings stale when freshness cannot be established.

## 7. Security, privacy, and data handling

- No cloud account, cloud relay, remote telemetry service, or third-party analytics is required for MVP operation.
- Pairing establishes a local credential; configuration and destructive writes reject absent or invalid credentials.
- Secrets must not appear in status/history/export payloads, normal logs, or browser-visible error text.
- API inputs are length- and range-checked. History/export requests are bounded to protect memory and responsiveness.
- Device reset, history deletion, and restore are explicit, confirmable operations with deterministic outcomes.
- Browser storage is limited to setup/session state and useful local cache. The app provides user-visible deletion controls.

This is a prototype threat model, not a claim that a hostile LAN is fully defended. Security behavior must be revisited before any remote access, cloud relay, or unattended deployment is proposed.

## 8. Explicit MVP non-goals

The MVP provides informational monitoring only. It explicitly excludes:

- **automatic watering**, irrigation control, pumps, valves, relays, or any other actuator path;
- **mains voltage** input, switching, sensing, wiring, or control;
- cloud accounts, required internet services, remote fleet management, or silent telemetry;
- clinical, medical, life-safety, emergency-monitoring, agricultural, agronomic, yield, diagnosis, or treatment **claims**;
- outdoor/weatherproof deployment;
- guaranteed plant-health outcomes;
- OTA updates until a reliable local recovery route exists;
- multi-user identity federation.

A future proposal that adds an actuator, mains interface, remote access, or regulated-domain claim requires a new architecture and safety review; it is not an incremental MVP feature.

## 9. Risk register

Evidence classes are deliberately separated: static review, automated test/simulation, bench validation, and field observation are not interchangeable.

| ID | Risk | Likelihood / impact | Mitigation in design | Verification evidence | Verification owner |
|---|---|---|---|---|---|
| R-01 | Probe drift, media variation, or corrosion produces misleading moisture state | High / High | Capacitive probes; per-zone dry/wet calibration; retain raw values; quality/uncalibrated states; no watering claims | Calibration unit tests, bench dry/wet/repeatability characterization, later field observation labeled non-generalizable | Firmware lead + integration owner |
| R-02 | Long probe leads couple noise or channels influence each other | Medium / High | Independent channels; defined grounding/conditioning; bounded source impedance; sequential sampling/settling if required by selected ADC | Schematic/layout review, SPICE where applicable, bench cross-channel/noise test | Hardware lead |
| R-03 | USB source, protection, or regulator cannot support peak radio/sensor current | Medium / High | Datasheet-backed power budget, input protection, bulk/decoupling, rail test points, normal-average target | Datasheet calculation, ERC/DRC, static power analysis, bench startup/peak/average current and rail droop | Hardware lead |
| R-04 | I2C address, pull-up, or bus-fault choices make a sensor unavailable or hang sampling | Medium / Medium | Select compatible addresses; calculate pull-ups/capacitance; driver timeouts and bus recovery; health flags | Datasheet review, analyzer checks, unit fault injection, bench disconnect/short recovery | Hardware + firmware leads |
| R-05 | Wi-Fi onboarding fails or credentials are lost | Medium / High | USB provisioning/recovery and deterministic reset independent of cloud; preserve diagnostics | Automated provisioning-state tests and bench failed-network recovery procedure | Firmware lead |
| R-06 | Local API writes are changed by an unauthorized LAN client | Medium / High | Locally established pairing credential, authenticated writes, input validation, no secret leakage | API authorization/negative tests and protocol review | Firmware lead |
| R-07 | Flash wear, corruption, or unbounded retention loses settings/history or destabilizes device | Medium / High | Bounded ring buffer; atomic versioned persistence; validated defaults; controlled write cadence | Persistence, migration, interrupted-write, corruption, and retention-bound tests | Firmware lead |
| R-08 | App shows stale, missing, or uncalibrated values as trustworthy | Medium / High | End-to-end quality states, explicit freshness metadata, offline/stale UI, raw/calibrated distinction | Shared fixture tests, app state tests, accessibility/usability review | App lead |
| R-09 | Export/backup is incomplete, malformed, or leaks secrets | Low / High | Versioned schemas, explicit user action, allowlisted fields, bounded generation, round-trip validation | Golden-file/round-trip tests and inspection proving secret fields absent | App + firmware leads |
| R-10 | Enclosure placement biases light/ambient readings or exposes electronics to moisture | Medium / Medium | Venting and optical placement constraints; leads separate wet area from enclosure; indoor-only labeling | Mechanical review, bench side-by-side sensor comparison, later labeled placement study | Hardware + integration owner |
| R-11 | Scope expands into watering, mains, remote control, or unsupported claims | Medium / High | Non-goals are architecture gates; backlog/PR review rejects actuator and mains paths without a new safety architecture | Architecture trace review on every milestone and release checklist | Project owner |
| R-12 | Component lifecycle or source changes invalidate electrical assumptions | Medium / Medium | Manufacturer+MPN source of truth in KiCad; datasheet/lifecycle checks; documented alternatives; BOM validation | Issue #2 selection record, lifecycle snapshots, schematic-property/BOM consistency checks | Hardware/BOM owner |

## 10. Architecture decisions and downstream gates

| Decision / gate | Baseline | Deferred owner |
|---|---|---|
| Controller family | ESP32-C3 module | Exact module and package: issue #2 |
| Power source | SELV USB 5 V only; regulated 3.3 V logic | Regulator/protection implementation: issues #2–#3 |
| Moisture capacity | Four independent capacitive channels | ADC vs mux and connector choice: issue #2 |
| Environmental sensors | One digital ambient and one digital light sensor per node | Exact MPN/address/package: issue #2 |
| Data authority | Device flash for calibration/config/history; app cache is non-authoritative | Persistence format/limits: issue #6 |
| App boundary | Versioned local HTTP; optional WebSocket; no board assumptions | Concrete schema/fixtures: issues #6–#7 |
| Recovery | USB path works without Wi-Fi/cloud | Concrete command/state flow: issue #6 |
| PCB | Editable KiCad carrier remains the implementation path | Schematic: issue #3; layout: issue #5 |
| BOM | KiCad symbol properties are the source of truth | Selection: issue #2; export pipeline: issue #4 |
| Evidence | Static, simulation, bench, and field evidence reported separately | Integration/release matrix: issue #8 |

## 11. Backlog dependency graph

```text
#1 Architecture baseline
  ├──> #2 Datasheet-backed component selection
  │       └──> #3 Editable schematic + ERC
  │               └──> #4 Schematic-source BOM ──┐
  │                       └──> #5 PCB + DRC ──────┼──> #8 Integration/release
  │                               └──> #6 Firmware MVP ──> #7 App MVP ──┘
  └────────────────────────────────────────────────────────> #7 (architecture contract)
```

The ordering rules are:

1. #2 starts only after this baseline is merged.
2. #3 requires #2 so symbol, footprint, and electrical choices are datasheet-backed.
3. #4 requires a populated schematic from #3; #5 requires both that schematic and its source-of-truth BOM conventions.
4. #6 requires the schematic pin/interface contract and first PCB/testability baseline (#3 and #5).
5. #7 requires this architecture and a testable firmware protocol from #6.
6. #8 requires completed BOM, PCB, firmware, and app work (#4–#7).

Parallel exploratory work may occur, but a dependent issue must not claim acceptance completion before its gates are satisfied.

## 12. Change control

A downstream PR that changes an interface, authority boundary, safety envelope, explicit non-goal, or dependency gate must:

1. update this document and any affected protocol/requirements document;
2. identify affected hardware, firmware, app, BOM, and verification owners;
3. add or update verification evidence appropriate to the risk;
4. avoid presenting static analysis or simulation as bench/field evidence.

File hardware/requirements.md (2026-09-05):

# Pot Pulse Hardware Requirements (Initial)

## Electrical
1. Input power: USB 5V SELV only.
2. Logic rail: regulated 3.3V for MCU and sensors.
3. Average current budget target: <= 250 mA in normal sampling mode.
4. Support at least 4 independent moisture sensing zones in MVP.
5. Sensor sampling interval configurable from 30 s to 15 min.

## Measurement and sensing
1. Report temperature and relative humidity from one digital ambient sensor.
2. Report illuminance from one digital light sensor per device.
3. Report per-zone calibrated moisture state using capacitive sensing channels.
4. Store timestamped readings with clear quality/status flags.

## Mechanical
1. Device footprint target: <= 120 mm x 80 mm custom carrier or equivalent module stack.
2. At least two mounting holes for enclosure integration.
3. User-serviceable sensor connectors (no permanent potted assembly).

## Connectivity and UX
1. Local setup path must work without cloud account.
2. Companion app must support live status + history export.
3. USB provisioning/recovery path required when Wi‑Fi onboarding fails.

## Environmental and safety
1. Indoor use only, nominal 10–35°C ambient.
2. No mains voltage exposure.
3. No medical, life-safety, or emergency-monitoring use.

## Cost target
- Prototype electronics + enclosure target range: **USD 35–60**
- Soft ceiling: **USD 75** (excluding phone/computer, tools, shipping, and tax)
- Per-line pricing remains TBD until live distributor sourcing.

## Verification requirements (later milestones)
- KiCad ERC pass (or documented exceptions)
- KiCad DRC pass (or documented exceptions)
- Datasheet-backed pinout and ratings validation
- Firmware build + test logs
- Companion app build + test logs
- Bring-up checklist with expected voltage/telemetry observations

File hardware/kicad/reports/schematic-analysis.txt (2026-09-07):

# Supplemental schematic analyzer output

Evidence class: static schematic analysis
Source: KiCad MCP `connections` and `circuit_patterns` operations on `pot-pulse.kicad_sch`

CONNECTIONS
- parser_path: cli
- incomplete: false
- components excluding power flags: 57
- nets: 27
- component types: C=13, D=1, F=1, J=6, L=1, R=12, TP=16, U=7
- power nets: +3V3=24 pins, +5V_PROTECTED=8, GND=60, VBUS=6
- potential issues: none reported

PATTERNS
- Four RC low-pass filters: R9/C10, R10/C11, R11/C12, R12/C13
- I2C: I2C_SCL/I2C_SDA on R4, R5, TP5, TP6, U2, U4, U5, U6
- USB: USB_CONN_DM/DP, USB_DM/DP and VBUS on F1, J1, TP1, TP7, TP8, U2, U7
- ESP32 microcontroller: U2
- ADS1115 16-bit four-channel I2C ADC: U4

TRIAGED HEURISTIC FALSE POSITIVES
- The pattern detector called U1/TPS62162 an LDO. The manufacturer datasheet and explicit SW/L1 topology establish a synchronous buck.
- The pattern detector called U6/VEML7700 a regulator. U6 is the ambient-light sensor.

AUTHORITATIVE ERC
`reports/erc.rpt`: 0 errors, 0 warnings.

LIMITS
No PCB, simulation, bench, EMC, thermal, environmental, calibration, or field evidence was produced.

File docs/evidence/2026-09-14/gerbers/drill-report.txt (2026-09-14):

Drill report for pot-pulse.kicad_pcb
Created on 2026-09-14T13:40:08+0000

Copper Layer Stackup:
    =============================================================
    L1 :  F.Cu                      front
    L2 :  In1.Cu                    in1
    L3 :  In2.Cu                    in2
    L4 :  B.Cu                      back

Drill file 'pot-pulse.drl' contains
    plated through holes:
    =============================================================
    T1  0.250mm  0.0098"  (2 holes)
    T2  0.300mm  0.0118"  (95 holes)
    T3  0.600mm  0.0236"  (4 holes)  (with 4 slots)
    T4  0.750mm  0.0295"  (12 holes)
    T5  1.000mm  0.0394"  (6 holes)

    Total plated holes count 119

Not plated through holes are merged with plated holes
    unplated through holes:
    =============================================================
    T6  0.650mm  0.0256"  (2 holes)
    T7  3.200mm  0.1260"  (3 holes)

    Total unplated holes count 5

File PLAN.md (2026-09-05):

# Pot Pulse — Implementation Plan

## Scope and architecture
Pot Pulse is a low-voltage sensing node plus local-first companion app. The normative MVP subsystem boundaries, interfaces, safety constraints, non-goals, and risk ownership are defined in [`docs/architecture.md`](docs/architecture.md). Downstream changes that alter those boundaries must update the architecture in the same pull request.

### Subsystems
1. **Sensor node (ESP32-C3 firmware)**
   - Samples soil moisture channels, ambient light, and temp/humidity.
   - Stores short local history and serves local API.
2. **Hardware platform (KiCad project)**
   - USB-powered sensing carrier with protection, connectors, and test points.
   - Supports common capacitive probe modules and I2C sensors.
3. **Companion app (local web app)**
   - Setup, zone naming, calibration, status/trends, export, and backup/restore.

## Technology choices (and rationale)
- **ESP32-C3**: low-cost Wi‑Fi + USB support, broad maker ecosystem.
- **KiCad**: editable open hardware source and reproducible outputs.
- **PlatformIO + ESP-IDF**: reproducible firmware builds and testable configuration.
- **TypeScript + Vite PWA**: fast cross-device local UI without app-store dependency.
- **CSV/JSON exports**: transparent, user-owned data portability.

## Milestones and dependency order

| Milestone | GitHub issue | Depends on | Exit gate |
|---|---:|---|---|
| Architecture and risk baseline | #1 | None | System context, interface ownership, non-goals, risk mitigations, and verification owners are agreed |
| Datasheet-backed component selection | #2 | #1 | Critical parts have manufacturer/MPN, electrical/package validation, lifecycle/availability snapshot, and KiCad field conventions |
| Editable schematic and ERC | #3 | #1, #2 | KiCad source captures the architecture interfaces and passes ERC or documents every exception |
| Schematic-source BOM | #4 | #2, #3 | `bom/bom.csv` is reproducibly exported from populated KiCad properties and non-schematic items are tracked separately |
| PCB layout and DRC | #5 | #3, #4 | Editable layout implements mechanical/testability constraints and passes DRC or documents every exception |
| Firmware MVP | #6 | #3, #5 | Pinned build, sampling/calibration/persistence/recovery implementation, `/api/v1` fixtures, and automated tests are reproducible |
| Companion app MVP | #7 | #1, #6 | Setup, status/history, accessible UX, export/backup/restore/delete flows build and test against the firmware contract |
| Integration and release package | #8 | #4, #5, #6, #7 | Bring-up/assembly docs and mature fabrication/release artifacts carry an explicit static/simulation/bench/field evidence matrix |

Dependency policy:

- A dependent milestone may be explored early, but it cannot claim acceptance completion until all listed gates have landed.
- Component and electrical decisions flow from manufacturer datasheets into KiCad properties and then into the exported BOM; the preliminary planning CSV is not a source of truth.
- Firmware owns physical sensor behavior and the device API; the app consumes the versioned protocol and does not encode board-level assumptions.
- Issue #8 is the only release/fabrication gate and must not promote placeholders or static checks as physical validation.

## Testing strategy
- **Static checks**: lint/format for firmware and app.
- **Firmware tests**: unit tests for calibration math and payload encoding; hardware-abstraction tests where practical.
- **App tests**: unit tests for state/store logic; integration tests for setup + export workflows.
- **Hardware verification**: ERC/DRC evidence, pinout checks, and measurement checklist in bring-up docs.
- **Boundary reporting**: explicitly separate static analysis, simulation, bench tests, and field usage.

## Packaging/distribution plan
- Firmware release artifacts: tagged binaries + flashing instructions.
- Companion app: local web bundle served from device or local host with offline fallback.
- Hardware: KiCad sources, PDF schematic, Gerbers/drills, BOM/CPL when applicable.

## Risks
The authoritative risk register is [`docs/architecture.md`](docs/architecture.md#9-risk-register). It assigns mitigations, evidence types, and verification owners for probe drift/corrosion, analog noise, power integrity, I2C faults, onboarding/recovery, API authorization, flash persistence, stale UI data, export privacy, enclosure bias/moisture exposure, scope creep, and component lifecycle.

Risk status must be updated where the evidence is produced. Static review, automated test/simulation, bench validation, and field observation remain distinct evidence classes.

## Explicit non-goals
- Autonomous irrigation or actuator control.
- Mains-powered designs.
- Agricultural certification/guarantees.
- Clinical or biological diagnosis.
- Cloud-first data architecture.

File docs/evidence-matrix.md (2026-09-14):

# Pot Pulse Evidence Matrix (Issue #8)

This matrix separates what is currently proven from what is only planned.

## Evidence classes

| Class | Meaning |
|---|---|
| Static analysis | Source/build/tool outputs without physical board execution |
| Simulation | Electrical simulation outputs |
| Bench validation | Measurements and behavior on assembled hardware |
| Field observation | Long-run use in deployment conditions |

## Current matrix (2026-09-14 run)

| Scope | Class | Evidence artifact | Status |
|---|---|---|---|
| Schematic electrical rules | Static analysis | `docs/evidence/2026-09-14/erc.rpt` | PASS (0 errors / 0 warnings) |
| PCB design rules | Static analysis | `docs/evidence/2026-09-14/drc.json` + `scripts/check_drc.py` | BLOCKED (5 unconnected) |
| Schematic↔PCB pad-net mapping | Static analysis | `hardware/kicad/cross_check_pads.py` run log | PASS |
| Firmware portable core tests | Static analysis | `pio test -e native` | PASS (19/19) |
| Firmware target build | Static analysis | `pio run -e esp32c3` | PASS |
| App typecheck/tests/build | Static analysis | `npm run typecheck && npm run test && npm run build` | PASS (47 tests) |
| BOM determinism/properties | Static analysis | `scripts/validate_bom.py` | PASS |
| Fabrication artifact preview | Static analysis | `docs/evidence/2026-09-14/pot-pulse-schematic.pdf`, `.../gerbers/*`, `.../pot-pulse-fabrication-preview.zip` | GENERATED (preview-only) |
| SPICE | Simulation | N/A in this run | NOT RUN |
| Board power-up/calibration | Bench validation | Planned in `docs/bring-up.md` | NOT RUN |
| Shelf deployment behavior | Field observation | N/A | NOT RUN |

## Interpretation

- This run proves reproducible source-level checks and exportability.
- It does **not** prove physical electrical behavior, calibration quality, EMC, thermal margins, or field reliability.
- Production release requires bench and (optionally) simulation evidence in addition to static checks.

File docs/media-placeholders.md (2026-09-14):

# Media Placeholders (Issue #8)

Real media has not been captured yet. The following are explicit placeholders only.

- `docs/media/placeholders/assembly-top-photo.md`
- `docs/media/placeholders/assembly-bottom-photo.md`
- `docs/media/placeholders/probe-wiring-photo.md`
- `docs/media/placeholders/enclosure-fit-photo.md`

Each file is intentionally a placeholder marker so release notes do not imply real bench/field imagery exists.

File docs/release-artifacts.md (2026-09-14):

# Fabrication/Release Artifact Workflow (Issue #8)

This document defines how to produce a mature release bundle and when to block it.

## Gate policy

A **mature** fabrication bundle requires:
1. ERC clean.
2. DRC gate clean (`scripts/check_drc.py` reports PASS).
3. BOM validation/export reproducible from schematic source of truth.

If DRC gate is blocked, any exported Gerbers/ZIP are **preview-only** artifacts.

## Commands

```sh
# 1) Static electrical checks
kicad-cli sch erc --severity-all --exit-code-violations \
  --output docs/evidence/<date>/erc.rpt hardware/kicad/pot-pulse.kicad_sch
kicad-cli pcb drc --schematic-parity --severity-all --exit-code-violations \
  --format json --output docs/evidence/<date>/drc.json hardware/kicad/pot-pulse.kicad_pcb
python3 scripts/check_drc.py docs/evidence/<date>/drc.json

# 2) BOM from schematic symbol properties
/tmp/pot-pulse-kicad-venv/bin/python scripts/validate_bom.py
/tmp/pot-pulse-kicad-venv/bin/python scripts/export_bom.py --output docs/evidence/<date>/bom.csv

# 3) Output artifacts (run only when gate is PASS for mature release)
kicad-cli sch export pdf --output docs/evidence/<date>/pot-pulse-schematic.pdf hardware/kicad/pot-pulse.kicad_sch
kicad-cli pcb export gerbers --layers F.Cu,B.Cu,F.Mask,B.Mask,F.SilkS,B.SilkS,Edge.Cuts \
  --output docs/evidence/<date>/gerbers hardware/kicad/pot-pulse.kicad_pcb
kicad-cli pcb export drill --format excellon --excellon-units mm --generate-map --map-format pdf \
  --generate-report --report-path docs/evidence/<date>/gerbers/drill-report.txt \
  --output docs/evidence/<date>/gerbers hardware/kicad/pot-pulse.kicad_pcb
(cd docs/evidence/<date> && zip -r pot-pulse-fabrication-release.zip bom.csv pot-pulse-schematic.pdf gerbers)
```

## 2026-09-14 execution result

- `scripts/check_drc.py docs/evidence/2026-09-14/drc.json` ->
  `BLOCKED: violations=0 unconnected_items=5 schematic_parity=145`
- A preview bundle was still exported for integration handoff:
  `docs/evidence/2026-09-14/pot-pulse-fabrication-preview.zip`
- Do not treat preview bundle as production-ready release output.

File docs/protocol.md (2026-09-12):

# Pot Pulse Device/App Protocol (MVP Contract)

**Status:** Proposed contract; implementation is owned by firmware issue #6 and consumer verification by app issue #7.

This protocol refines the subsystem boundary in [`architecture.md`](architecture.md). The architecture owns safety, trust, and data-authority rules; this document owns transport resources and payload semantics. A change that affects both must update both documents together.

## Transport and availability

- Primary transport: local HTTP with JSON payloads over the LAN.
- Optional transport: an authenticated WebSocket stream for best-effort live updates.
- Setup/recovery transport: USB serial commands for provisioning, diagnostics, and reset.
- HTTP remains the functional fallback when WebSocket delivery is unavailable.
- No cloud relay, cloud account, or internet connection is required.

## Security boundary

The local network is a transport boundary, **not a trusted authorization boundary**.

- Firmware must require a locally established pairing credential for configuration, calibration, export, backup, restore, history deletion, reset, and other state-changing or user-data operations.
- An absent, invalid, or expired credential must fail closed without changing device state.
- A minimal read-only first-run status response may be exposed before pairing only if it contains no credentials, network secrets, retained history, user metadata, or stable tracking identifier.
- Pairing and credential-storage mechanics are finalized in issue #6, but unauthenticated configuration writes are prohibited by the architecture baseline.
- Secrets must not be returned by status/history/export/backup resources or written to normal diagnostic logs.

## Resource contract

All resources are rooted at `/api/v1`. Firmware owns server behavior and canonical device data. The app owns client validation, user consent, transfer, local file handling, and presentation.

### Read and observation resources

- `GET /api/v1/status`
  - Returns device health, time quality, device-level environmental observations, and the latest moisture observation for every configured zone.
  - Must distinguish current, stale, sensor-error, and uncalibrated states.
- `GET /api/v1/history?zone=<id>&from=<ts>&to=<ts>&limit=<n>`
  - Returns a bounded page of retained samples.
  - Firmware validates the zone, time range, and maximum page size.
- Authenticated WebSocket subscription (optional)
  - Emits the same reading schema used by status/history.
  - Delivery is best effort; reconnecting clients recover through bounded HTTP history rather than assuming exactly-once events.

### State-changing and user-data resources

Each resource below requires a valid pairing credential and server-side schema/range validation.

- `POST /api/v1/calibration/<zone_id>`
  - Stores validated dry/wet reference points and calibration metadata for one moisture zone.
- `POST /api/v1/config`
  - Updates allowed settings such as sampling interval, thresholds, zone metadata, and retention policy.
- `POST /api/v1/export`
  - Generates a canonical, versioned CSV or JSON history export after explicit user action.
  - Firmware owns export content; the app owns download and user-selected file storage.
- `POST /api/v1/backup`
  - Generates a versioned backup of restorable settings, calibration, and zone metadata.
  - Credentials, network secrets, and transient samples are excluded unless a later version documents and secures them explicitly.
- `POST /api/v1/restore`
  - Accepts a bounded versioned backup, validates the complete payload before mutation, and applies it atomically or not at all.
  - Incompatible versions and malformed data are rejected without changing current settings.
- `DELETE /api/v1/history`
  - Deletes retained readings only after an explicit confirmation value in the request.
  - The response states whether deletion completed; partial success is not reported as complete.
- `POST /api/v1/reset`
  - Performs the documented reset level only after an explicit confirmation value.
  - Reset semantics must state whether configuration, calibration, history, pairing, and network settings are retained or erased.

The concrete pairing resource, headers, status codes, size limits, pagination shape, and confirmation-value format must be frozen with shared fixtures in issue #6 before issue #7 claims integration completion.

### Frozen mechanics (issue #6 implementation)

- **Pairing flow (nonce-based, out-of-band confirmation):**
  1. `POST /api/v1/pair/request` — unauthenticated, returns `202` with
     `{"pair_id":"<8 hex>","nonce":"<8 hex>","confirm_over":"usb-serial"}`.
     Only one pending request at a time (`409` while active). Contains no
     user data or stable identifiers.
  2. A human runs `pair confirm <pair_id>` on the device's USB serial
     console; the device mints a 32-hex-char token printed **only** on the
     serial console.
  3. The app sends `X-PotPulse-Token: <token>` on protected resources.
     Invalid/absent token → `401 {"error":"unauthorized"}`; device state is
     never changed on failed auth (fail closed).
- **Pre-pairing status:** `GET /api/v1/status` is readable unauthenticated
  but omits `device_id` (no stable tracking identifier) and never returns
  retained history, calibration, names, or credentials.
- **Zone identity:** persistent ids `z1`..`z4`; `zone_names` in
  `POST /api/v1/config` are display metadata only. History responses echo
  `zone_id`.
- **Headers/auth:** `X-PotPulse-Token`. Status codes: `200/202` success,
  `400` validation, `401` auth, `409` conflict (pairing), `422` incompatible
  backup version, `428` confirmation required (history delete).
- **Limits:** request bodies ≤ 8 KiB; `limit` 1..500 (default 100);
  zone name ≤ 32 chars; `sample_interval_ms` 30000..900000.
- **Confirmation words:** history delete requires query `confirm=confirm`;
  reset requires body `{"level":"full-firmware","confirm":"confirm"}`.
  `full-firmware` erases pairing/config/calibration/history and RETAINS
  Wi-Fi credentials (documented reset semantics).
- **Error shape:** `{"error":"<code>","message":"<safe text>"}`; messages
  never include secrets, tokens, or config values.
- **Timestamps:** ISO-8601 UTC second precision when synchronized, else
  `"timestamp":null` + `time_quality:"relative"`. `monotonic_ms` is always
  present for ordering.

## Status payload sketch

Illuminance, temperature, and humidity are **device-level** observations because the MVP has one light sensor and one ambient sensor per node. Only moisture is per-zone.

```json
{
  "schema_version": 1,
  "device_id": "string",
  "timestamp": "ISO-8601-or-null",
  "time_quality": "synchronized|relative|unknown",
  "environment": {
    "light_lux": 0.0,
    "light_quality": "ok|sensor_error|stale",
    "temperature_c": 0.0,
    "humidity_rh": 0.0,
    "ambient_quality": "ok|sensor_error|stale"
  },
  "zones": [
    {
      "zone_id": "string",
      "moisture_raw": 0,
      "moisture_calibrated": 0.0,
      "state": "dry|ok|wet|unknown",
      "quality": "ok|sensor_error|uncalibrated|stale"
    }
  ]
}
```

Normative payload rules:

- `moisture_raw` is retained so calibration can be audited or replaced.
- `moisture_calibrated` and `state` must not imply a valid calibration when quality is `uncalibrated`.
- Unsynchronized time is represented explicitly; the app must not render it as exact wall-clock time.
- Missing or failed sensor readings are represented by quality state and nullable/omitted measurement fields in the final schema, never by fabricated normal values.
- Unknown additive fields are ignored by clients; incompatible breaking changes require a new API/schema version.

## Ownership and failure behavior

- Device flash is authoritative for device configuration, calibration, zone metadata, and bounded history.
- Browser storage is a disposable cache and may contain app presentation state. It is not authoritative device history.
- Loss of Wi-Fi does not stop scheduled sampling or bounded retention.
- Loss of WebSocket delivery falls back to HTTP status/history.
- The app labels cached or unsynchronized readings and does not silently manufacture missing samples.
- Export and backup occur only after user action. Files stay local unless the user independently moves or shares them.
- Restore, delete, and reset are deterministic, confirmable operations with all-or-nothing outcomes where device state is mutated.

## Out of scope for MVP

- Third-party cloud API contracts or cloud relay
- Multi-user identity federation
- Remote device fleet management
- Remote actuator control or watering automation
- Mains-powered or mains-connected interfaces

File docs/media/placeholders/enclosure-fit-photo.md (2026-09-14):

# PLACEHOLDER — Enclosure fit photo

Status: placeholder only. Replace with real enclosure clearance/fit evidence.

Evidence class: media placeholder (not bench evidence).

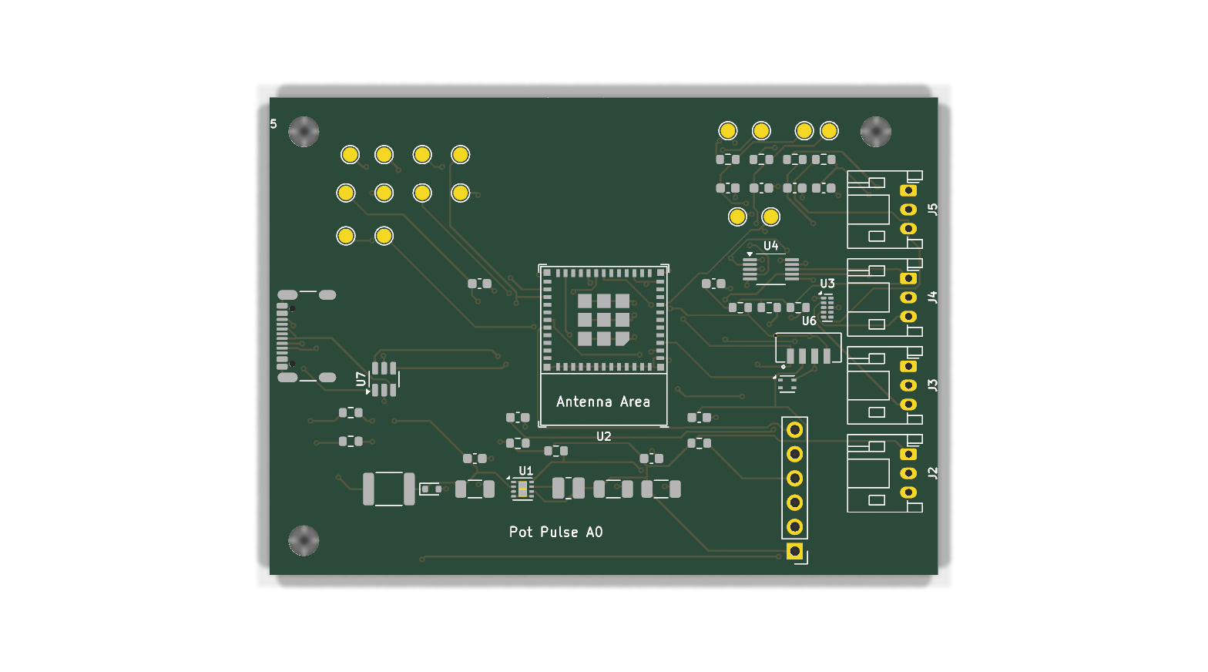
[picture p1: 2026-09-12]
hardware/kicad/reports/render-top.png

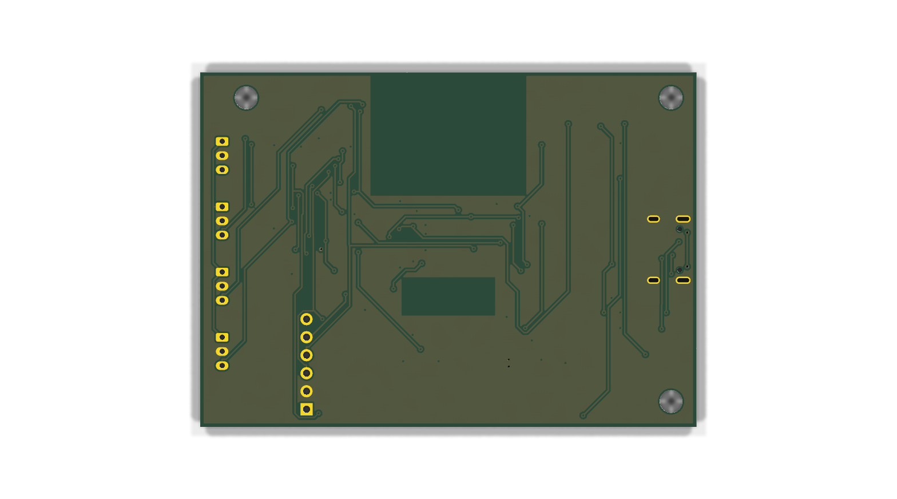
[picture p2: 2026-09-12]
hardware/kicad/reports/render-bottom.png

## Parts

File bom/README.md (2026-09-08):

# Pot Pulse bill of materials

The editable KiCad schematic is the source of truth for every board-mounted purchased part. `bom/bom.csv` is a deterministic export; do not hand-edit it. Procurement items that do not have schematic symbols are tracked separately in `bom/non-schematic-items.csv`.

## Files

- `bom/bom.csv` — grouped board BOM generated from KiCad properties.
- `bom/non-schematic-items.csv` — probes, cable, enclosure, fasteners, and conditional debug tooling.
- `scripts/export_bom.py` — deterministic schematic-to-CSV export.
- `scripts/validate_bom.py` — property, export, schema, quantity, and procurement-list checks.
- `bom/preliminary-bom.csv` — historical planning input only; it is not authoritative.

## KiCad property contract

Every purchased symbol (`in_bom=yes`, excluding power symbols) must carry:

- `Manufacturer` and exact `MPN`
- assigned `Footprint`
- `Supplier` (`Unassigned` is explicit when no source is selected)
- `Supplier PN` when a supplier is assigned
- `Source URL`
- `Estimated Unit Cost USD` (numeric dated estimate or explicit `TBD - live quote required`)
- `Price Snapshot Date`
- `Datasheet`
- `BOM Comments`

`Value` remains the electrical/display value and never replaces the MPN. The generator in `hardware/kicad/generate_schematic.py` owns these properties so regenerating the schematic does not erase BOM data.

## Update workflow

1. Verify the exact manufacturer MPN and package against the manufacturer datasheet.
2. Query the intended supplier by exact MPN. Confirm manufacturer identity, package, and supplier PN; same-MPN clone records are not accepted as substitutions.
3. Update the component call and, when applicable, `SOURCING` in `hardware/kicad/generate_schematic.py` with the source URL, unit-price snapshot, and snapshot date. Never copy current stock or price into the BOM without recording the date.
4. Regenerate the editable schematic:

   ```sh
   KICAD_SYMBOL_DIR=/usr/share/kicad/symbols \
     /tmp/pot-pulse-kicad-venv/bin/python hardware/kicad/generate_schematic.py
   ```

5. Export and validate:

   ```sh
   /tmp/pot-pulse-kicad-venv/bin/python scripts/export_bom.py
   /tmp/pot-pulse-kicad-venv/bin/python scripts/validate_bom.py
   ```

6. Review the diff in both `pot-pulse.kicad_sch` and `bom/bom.csv`. Re-run native ERC because regeneration touches the electrical source.
7. Re-query all prices, stock, lifecycle state, MOQ, and order multiples immediately before purchasing. A dated estimate is not availability or a reservation.

## Current sourcing boundary

The 2026-09-08 LCSC/JLCSearch query found exact MPN records for 18 of 21 unique schematic MPNs (21 of 24 grouped BOM lines). Three MPNs (`GRM188R71C105KA12D`, `GRM31CR61C226ME15L`, and `VLS252012T-2R2M1R3`) remain explicitly unassigned and require live quotes. The ST `USBLC6-2SC6` and TI `TPD4E05U06DQAR` retain the manufacturer-validated LCSC records from the 2026-09-05 selection snapshot; ambiguous newer same-MPN search hits were not substituted.

The numeric extended total in `bom/bom.csv` is therefore a **partial board-component estimate**, excluding the three unquoted schematic lines, all non-schematic items, PCB fabrication, assembly, shipping, tax, setup fees, and spare quantities.

## Evidence boundary

This pipeline proves static property completeness and deterministic export only. Supplier records and costs are dated catalog evidence. It does not prove present stock, successful ordering, assembly yield, electrical behavior, bench performance, or field performance.

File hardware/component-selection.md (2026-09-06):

# Datasheet-backed component selection

**Status:** selected for the first schematic pass in issue #3

**Evidence date:** 2026-09-06 UTC

**Machine-readable record:** [`component-selection.csv`](component-selection.csv)

This document freezes the critical component choices needed to start schematic capture. Manufacturer documentation is the electrical source of truth. Distributor quantities are only a dated availability snapshot; they are not reservations, price guarantees, or lifecycle guarantees.

No KiCad schematic exists at this milestone. Therefore these values are staged in `component-selection.csv`; issue #3 must copy them into every placed symbol using the property conventions below. The final BOM source of truth remains the KiCad schematic, not this document or `bom/preliminary-bom.csv`.

## 1. Selected topology

```text
USB-C VBUS
  -> 0.50 A hold PPTC
  -> 5 V VBUS TVS clamp
  -> 5 V input rail
  -> TPS62162 fixed 3.3 V / 1 A buck
  -> ESP32-C3-MINI-1-H4X + ADS1115 + SHT40 + VEML7700 + probes

USB-C D+/D-
  -> USBLC6-2SC6
  -> ESP32-C3 GPIO19/GPIO18 native USB

Four SEN0193 probes
  -> four keyed PH2.0 connectors
  -> TPD4E05U06 quad low-leakage ESD array
  -> per-channel RC footprints
  -> ADS1115 AIN0..AIN3

ESP32-C3 I2C
  -> ADS1115 at 0x48 (ADDR = GND)
  -> SHT40 at 0x44
  -> VEML7700 at 0x10
```

This preserves four electrically distinct moisture channels and avoids consuming the ESP32-C3 ADC channels for long external analog leads. The selected I2C addresses do not conflict.

## 2. Selection summary

| Class | Selected manufacturer / MPN | Critical validated facts | Why selected |
|---|---|---|---|
| MCU module | Espressif `ESP32-C3-MINI-1-H4X` | Recommended 4 MB module variant; 3.0–3.6 V; −40 to +105 °C; external supply capability at least 0.5 A; 13.2 × 16.6 × 2.4 mm; GPIO18=`USB_D-`, GPIO19=`USB_D+`; GPIO20/21 expose UART0 | Meets the architecture’s ESP32-C3, Wi-Fi, native-USB recovery, and temperature needs while avoiding the NRND N4 revision |
| ADC | Texas Instruments `ADS1115IDGSR` | 2.0–5.5 V; four single-ended inputs; 16 bit; 8–860 SPS; −40 to +125 °C; VSSOP-10; ADDR=GND gives 7-bit address `0x48`; analog pins limited to GND−0.3 V through VDD+0.3 V | One part provides all four independent channels with deterministic I2C ownership and ample rate for 30 s minimum sample intervals |
| Regulator | Texas Instruments `TPS62162DSGR` | 3–17 V input; fixed 3.3 V; up to 1 A; 17 µA typical quiescent current; −40 to +125 °C junction; WSON-8 2 × 2 mm with exposed pad; 2.2 µH-class typical application | Provides margin above the module’s 0.5 A supply recommendation without the worst-case heat of a 5 V-to-3.3 V SOT-23 LDO |
| Ambient sensor | Sensirion `SHT40-AD1B-R2` | 1.08–3.6 V; 0–100 %RH and −40 to +125 °C operating ranges; I2C address `0x44`; DFN-4; manufacturer lists the exact orderable MPN | Fits the 3.3 V rail and does not collide with the ADC or light sensor |
| Light sensor | Vishay `VEML7700-TR` | 2.5–3.6 V; 0–140 klx; 16-bit result; −25 to +85 °C; fixed I2C address `0x10`; 6.8 × 2.35 × 3.0 mm | Covers indoor low light through bright-window conditions and uses the shared 3.3 V bus |
| Moisture probe | DFRobot `SEN0193` (quantity 4) | 3.3–5.5 V input; analog output documented up to 3.0 V; 5 mA; PH2.0-3P cable; 98 × 23 mm | Traceable capacitive probe with manufacturer documentation; compatible with a 3.3 V ADC when powered at 3.3 V |
| USB connector | GCT `USB4105-GF-A` | USB Type-C USB 2.0 receptacle; collective VBUS rating 5 A; 48 VDC connector rating; −40 to +85 °C | Exposes power, CC, and USB 2.0 data in a mechanically anchored receptacle |
| Probe connector | JST `S3B-PH-K-S(LF)(SN)` (quantity 4) | Right-angle 3-position PH, 2.0 mm pitch; 2 A; 100 V; −40 to +105 °C | Matches the SEN0193 cable family and supports keyed, user-serviceable probes |
| USB ESD | STMicroelectronics `USBLC6-2SC6` | Two-line, low-capacitance USB 2.0 ESD protection in SOT-23-6 | Purpose-designed protection for the native USB data pair |
| VBUS TVS | onsemi `ESD5Z5.0T1G` | 5 V reverse standoff; 6.2 V minimum breakdown; 174 W peak pulse; SOD-523 | Adds a dedicated clamp for USB VBUS transients instead of misusing the data-line array |
| Probe ESD | Texas Instruments `TPD4E05U06DQAR` | Four channels; 0–5.5 V signal range; 0.5 pF; 10 nA maximum leakage; −40 to +125 °C; active production | Protects all four analog lines with leakage low enough not to dominate sensor measurements |
| Input fuse | Bourns `MF-MSMF050-2` | 15 V maximum; 0.50 A hold and 1.00 A trip at 23 °C; −40 to +85 °C; 1812 | Adds resettable USB input overcurrent protection while preserving the module’s required 0.5 A supply capability |

## 3. Electrical compatibility and schematic constraints

### Power

- The TPS62162’s 1 A rating exceeds the ESP32-C3 module’s requirement for an external supply capable of at least 0.5 A and leaves headroom for four 5 mA probes plus the digital sensors. This is a **static capacity comparison**, not a measured current budget.
- Do not replace the buck with an AP2112K-class SOT-23 LDO without a thermal review. At the architecture’s 250 mA average-current ceiling, `(5.0 V - 3.3 V) × 0.25 A = 0.425 W` before tolerances; radio bursts increase instantaneous dissipation.
- Implement the TPS62162 manufacturer application/layout guidance, including the exposed-pad ground, local input/output ceramics, short switch-node loop, and an inductor selected from the allowed inductance/current region. Issue #3 must record exact passive MPNs.
- Place the MF-MSMF050-2 immediately after VBUS. Its 0.50 A hold value is not proof that radio bursts will be trouble-free; bench verification in issue #8 must check startup, peak current, rail droop, and nuisance trips.

### Moisture acquisition

- Power all SEN0193 probes from 3.3 V so their outputs remain in the ADS1115 supply domain.
- Route one probe signal to each of AIN0–AIN3. Keep ADDR at GND (`0x48`).
- The ADS1115 programmable full-scale setting does **not** relax the absolute input pin limit. Protect and filter each input so it remains within GND−0.3 V to VDD+0.3 V.
- Place the TPD4E05U06 at the connector boundary, followed by footprints for a series resistor and shunt capacitor per channel. Exact RC values require cable/noise characterization; issue #3 should provide conservative defaults and issue #8 should measure settling, cross-channel coupling, open-probe behavior, and dry/wet repeatability.
- `SEN0193` selection does not establish soil-water-content accuracy. Firmware must retain raw readings and require per-zone dry/wet calibration as defined by the architecture.

### I2C

| Device | 7-bit address | Address behavior |
|---|---:|---|
| VEML7700 | `0x10` | Fixed |
| SHT40-AD1B-R2 | `0x44` | Fixed for the selected orderable variant |
| ADS1115 | `0x48` | ADDR tied to GND; other strap options are `0x49`–`0x4B` |

Use one set of calculated 3.3 V pull-ups for the assembled bus. Do not populate independent breakout-board pull-ups. Confirm total bus capacitance after layout and use firmware timeouts/bus recovery as required by risk R-04.

### USB and debug

- Connect GPIO18 to USB D− and GPIO19 to USB D+ through the USBLC6-2SC6 protected path. Keep the ESD device adjacent to the receptacle with a short ground return.
- Add independent 5.1 kΩ Rd resistors from CC1 and CC2 to ground for a USB-C sink; the connector rating does not replace Type-C configuration resistors or input current limiting.
- Expose GPIO20/U0RXD, GPIO21/U0TXD, EN, boot strapping access, 3.3 V, and GND as documented test/programming points. Native USB is the normal recovery path; UART pads remain the fallback.
- Respect Espressif’s antenna keepout. No copper, components, enclosure metal, or cable bundle should obstruct the module antenna region.

### Sensor placement

- The SHT40 is open-cavity. Follow Sensirion’s land pattern: do not place copper under the body other than pin pads, and keep it away from the regulator, module, indicator LEDs, and enclosure heat traps.
- The VEML7700 optical aperture must face a defined enclosure opening and be shielded from status-LED spill. Its −25 °C lower operating limit still exceeds the MVP’s 10 °C minimum.

## 4. Sourceability snapshot

The exact quantities are captured in `component-selection.csv`. On 2026-09-06 UTC, the public LCSC/JLC catalog reported positive stock for every selected board-mounted critical part:

- `ESP32-C3-MINI-1-H4X` / C41349510: 911
- `ADS1115IDGSR` / C37593: 14,470
- `TPS62162DSGR` / C40256: 439
- `SHT40-AD1B-R2` / C2909890: 20,692
- `VEML7700-TR` / C504893: 4,861
- `USB4105-GF-A` / C3020560: 11,505
- `S3B-PH-K-S(LF)(SN)` / C157929: 227,315
- `USBLC6-2SC6` (ST) / C7519: 36,380
- `ESD5Z5.0T1G` (onsemi) / C82044: 315,966
- `TPD4E05U06DQAR` (TI) / C138714: 94,387
- `MF-MSMF050-2` / C17313: 19,184

DFRobot’s manufacturer store listed `SEN0193` as a current purchasable product at the snapshot date but did not expose a quantity. DigiKey also listed the exact MPN as active and “buy now, ships today.” Recheck quantities, authorized-source status, lead time, and prices immediately before purchasing; these values are evidence of sourceability on the stated date only.

## 5. Lifecycle assessment

- **Recommended:** Espressif lists `ESP32-C3-MINI-1-H4X` as a recommended module variant in datasheet v2.2.
- **Active / Production:** TI’s current datasheet orderable addenda mark `ADS1115IDGSR`, `TPS62162DSGR`, and `TPD4E05U06DQAR` active and in production.
- **Current orderable/catalog parts:** the current Sensirion datasheet lists `SHT40-AD1B-R2`; Vishay, GCT, ST, onsemi, Bourns, JST, and DFRobot maintain current product/catalog documentation for the selected parts.
- These checks are a point-in-time lifecycle screen, not a product-longevity guarantee. Issue #4 must repeat lifecycle and stock checks before an order is generated.

## 6. Rejected alternatives

| Alternative | Decision | Reason |
|---|---|---|
| `ESP32-C3-MINI-1-N4` | Reject | Espressif datasheet v2.2 explicitly marks this older chip-revision module NRND. Use the recommended H4X variant. |
| ESP32-C3 development board mounted on the carrier | Reject for production schematic | Duplicates USB/power circuitry, complicates mechanical integration, and weakens the KiCad/BOM source-of-truth. A dev kit remains useful only as firmware test equipment. |
| ESP32-C3 internal ADC for all probes | Reject | Four long external analog channels benefit from one dedicated ADC, explicit protection/filtering, deterministic channel mapping, and freedom from MCU ADC resource constraints. |
| ADS1015 | Reject | Pin-compatible and faster, but its 12-bit resolution offers no benefit at the slow sampling interval; ADS1115’s 16-bit output gives more calibration headroom. |
| AP2112K-3.3 or similar SOT-23 LDO | Reject | The 1.7 V drop produces 0.425 W at the 250 mA average-current ceiling and has poor burst/thermal margin compared with the selected buck. |
| SHT31-class sensor | Reject | Valid but larger/older for this design; SHT40 is current, low power, supports 3.3 V directly, and has a non-conflicting address. |
| BH1750 breakout/module | Reject | Breakouts create duplicate regulators/pull-ups and a weak BOM boundary. The VEML7700 IC is a direct 3.3 V, current manufacturer-supported option with a defined optical package. |
| Anonymous “capacitive v1.2” probes | Reject | Seller-dependent construction and missing traceable MPN/datasheet undermine calibration, lifecycle, and repeatability evidence. |
| JST-XH probe connector | Reject | The selected SEN0193 cable uses PH2.0-3P; XH’s 2.5 mm family would require a different harness and invite assembly mistakes. |
| Same-MPN USBLC6/TPD4 clones | Reject | Select the named ST and TI manufacturer records; identical marketing part strings from unrelated manufacturers are not assumed electrically equivalent. |

## 7. KiCad symbol-property conventions

Issue #3 must populate these properties on every real schematic symbol. Do not encode multiple physical parts in one comma-separated MPN; use separate symbols or explicit non-schematic procurement rows.

| Property | Required | Format and ownership |
|---|---|---|
| `Manufacturer` | Yes for every purchased part | Manufacturer’s canonical name, for example `Texas Instruments` |
| `MPN` | Yes for every purchased part | One exact orderable manufacturer part number; no generic family names |
| `Datasheet` | Yes for critical ICs/modules/connectors/protection | Direct manufacturer datasheet or manufacturer product-document URL |
| `LCSC` | When an exact LCSC match is selected | Exact `C` number, for example `C40256`; never a search URL |
| `DigiKey` | When a DigiKey SKU is selected | Exact orderable DigiKey part number, not the manufacturer MPN |
| `Mouser` | When a Mouser SKU is selected | Exact orderable Mouser part number |
| `BOM Comments` | As needed | Assembly, substitution, variant, orientation, or procurement caveats |
| KiCad `DNP` flag | As needed | Population state; explain conditional use in `BOM Comments` |

Rules:

1. `Manufacturer` + `MPN` are the universal identity and must be written together.
2. `Value` remains the electrical/display value; it must not substitute for `MPN`.
3. `Footprint` must match the selected package and datasheet land pattern before issue #3 closes.
4. Supplier fields are optional cross-references and must be revalidated before ordering.
5. The schematic is authoritative once it exists. `bom/bom.csv` is generated from it in issue #4; `component-selection.csv` is only the issue #3 import checklist.
6. Generic passives introduced during schematic capture need exact MPNs too before issue #4 claims BOM completeness.

## 8. Evidence and remaining validation

### Completed here (static evidence)

- Manufacturer datasheet review for electrical limits, package, pin/interface behavior, and current orderable status.
- I2C address compatibility check.
- Static power-path capacity comparison.
- Dated sourceability lookup from public distributor/manufacturer listings.

### Not completed here

- No KiCad schematic exists, so symbol-to-pin, symbol-to-footprint, ERC, and property-completeness checks are deferred to issue #3.
- No SPICE simulation was applicable because no schematic/subcircuit netlist exists.
- No bench evidence exists for current draw, regulator ripple, USB recovery, probe range/noise, calibration repeatability, or ESD behavior.
- No field evidence exists; the selected probes do not establish agronomic accuracy.
- Mouser API inventory could not be queried because the cron environment did not expose `MOUSER_SEARCH_API_KEY`; no Mouser quantity is claimed.

## 9. Manufacturer sources

- Espressif, *ESP32-C3-MINI-1 & MINI-1U Datasheet v2.2*, Tables 1-1, 3-1, and 6-2.
- Texas Instruments, *ADS111x Datasheet Rev. E*, features, Sections 6.1 and 7.5.1.1, and orderable addendum.
- Texas Instruments, *TPS6216x Datasheet Rev. E*, Sections 5, 7.3, 9.2, and orderable addendum.
- Sensirion, *SHT4x Datasheet v7.3*, highlights, quick-start/I2C sections, Section 5, and orderable table.
- Vishay, *VEML7700 Datasheet Rev. 1.8*, features, ratings, and device-address section.
- DFRobot, *SEN0193 manufacturer wiki/product documentation*.
- GCT, *USB4105 Product Specification Rev. A3*, Section 4 ratings.
- JST, *PH Connector catalog*, specifications and 3-circuit header table.
- STMicroelectronics, *USBLC6-2 datasheet/product page*.
- onsemi, *ESD5Z Series ESD Protection Diodes datasheet/product page*.
- Texas Instruments, *TPDxE05U06 Datasheet Rev. O*, features, Section 6.3, and orderable addendum.
- Bourns, *MF-MSMF Series PTC Resettable Fuses*, ratings table and environmental characteristics.

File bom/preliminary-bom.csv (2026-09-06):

Item | Qty | Function | Candidate_Part_or_Module | Package_or_Module | Manufacturer | MPN | Estimated_Unit_Cost_USD | Source_URL | Planning_Status | Notes
MCU module | 1 | Main controller with Wi-Fi and native USB | ESP32-C3-MINI-1-H4X | SMD module, 13.2 x 16.6 mm | Espressif Systems | ESP32-C3-MINI-1-H4X | TBD - recheck before order | https://www.lcsc.com/product-detail/C41349510.html | SELECTED_FOR_SCHEMATIC | Recommended module variant; preserve antenna keepout; 4 MB flash
Ambient sensor | 1 | Temperature and humidity sensing | SHT40-AD1B-R2 | DFN-4, 1.5 x 1.5 mm | Sensirion | SHT40-AD1B-R2 | TBD - recheck before order | https://jlcpcb.com/partdetail/Sensirion-SHT40_AD1BR2/C2909890 | SELECTED_FOR_SCHEMATIC | I2C 0x44; open cavity; no copper under body except pin pads
Light sensor | 1 | Ambient light measurement | VEML7700-TR | 4-pin SMD, 6.8 x 2.35 mm | Vishay | VEML7700-TR | TBD - recheck before order | https://www.lcsc.com/product-detail/C504893.html | SELECTED_FOR_SCHEMATIC | I2C 0x10; enclosure needs an optical aperture and LED spill control
Moisture probe | 4 | Per-pot capacitive moisture measurement | SEN0193 | Probe module, PH2.0-3P | DFRobot | SEN0193 | TBD - recheck before order | https://www.dfrobot.com/product-1385.html | SELECTED_FOR_SCHEMATIC | Power at 3.3 V; bench-characterize output and calibrate each zone
ADC | 1 | Four independent moisture channels | ADS1115IDGSR | VSSOP-10 | Texas Instruments | ADS1115IDGSR | TBD - recheck before order | https://www.lcsc.com/product-detail/C37593.html | SELECTED_FOR_SCHEMATIC | I2C 0x48 with ADDR tied to GND; AIN0 through AIN3 map one-to-one to probes
Voltage regulator | 1 | 3.3 V regulation from USB input | TPS62162DSGR | WSON-8-EP, 2 x 2 mm | Texas Instruments | TPS62162DSGR | TBD - recheck before order | https://www.lcsc.com/product-detail/C40256.html | SELECTED_FOR_SCHEMATIC | Fixed 3.3 V / 1 A buck; implement manufacturer layout and external LC network
USB data ESD | 1 | Protect native USB D+ and D- | USBLC6-2SC6 | SOT-23-6 | STMicroelectronics | USBLC6-2SC6 | TBD - recheck before order | https://www.lcsc.com/product-detail/C7519.html | SELECTED_FOR_SCHEMATIC | Use exact ST manufacturer record; place beside receptacle
USB VBUS TVS | 1 | Clamp USB input ESD and transients | ESD5Z5.0T1G | SOD-523 | onsemi | ESD5Z5.0T1G | TBD - recheck before order | https://www.lcsc.com/product-detail/C82044.html | SELECTED_FOR_SCHEMATIC | 5 V standoff; place after PPTC at connector entry
Probe input ESD | 1 | Protect four external analog inputs | TPD4E05U06DQAR | USON-10, 1 x 2.5 mm | Texas Instruments | TPD4E05U06DQAR | TBD - recheck before order | https://www.lcsc.com/product-detail/C138714.html | SELECTED_FOR_SCHEMATIC | Four channels; low leakage; add per-channel RC footprints
USB input fuse | 1 | Resettable VBUS overcurrent protection | MF-MSMF050-2 | 1812 | Bourns | MF-MSMF050-2 | TBD - recheck before order | https://www.lcsc.com/product-detail/C17313.html | SELECTED_FOR_SCHEMATIC | 0.50 A hold / 1.00 A trip at 23 C; bench-check radio burst margin
USB-C connector | 1 | Power and native USB data | USB4105-GF-A | USB-C SMT top mount | Global Connector Technology | USB4105-GF-A | TBD - recheck before order | https://www.lcsc.com/product-detail/C3020560.html | SELECTED_FOR_SCHEMATIC | USB sink; add independent 5.1 kOhm Rd resistors on CC1 and CC2
Moisture connector | 4 | Keyed probe connectivity | S3B-PH-K-S(LF)(SN) | Right-angle THT, PH 2.0 mm, 3 position | JST | S3B-PH-K-S(LF)(SN) | TBD - recheck before order | https://www.lcsc.com/product-detail/C157929.html | SELECTED_FOR_SCHEMATIC | Matches SEN0193 cable family; mark VCC/GND/SIG orientation
User controls and indicators | 1 | Local interaction | Pushbutton plus non-color-only LED indicators | Mixed | TBD | TBD | TBD - live sourcing required | TBD | PLANNING_ONLY | Exact switch, LED, and resistors selected during schematic capture
USB cable | 1 | Power and setup connection | USB-C data-capable cable | Cable | TBD | TBD | TBD - live sourcing required | TBD | PLANNING_ONLY | Non-schematic procurement item; exact cable selected in issue #4
Enclosure | 1 | Mechanical housing | 3D-printed or off-the-shelf enclosure | Mechanical | TBD | TBD | TBD - fabrication quote required | TBD | PLANNING_ONLY | Non-schematic procurement item; include venting, light aperture, and probe lead routing
Fasteners/standoffs set | 1 | Assembly hardware | M2/M3 screws, nuts, standoffs | Mechanical | TBD | TBD | TBD - live sourcing required | TBD | PLANNING_ONLY | Non-schematic procurement item; select after PCB thickness and enclosure are fixed
Debug/programming adapter | 1 | Firmware flashing and bring-up | Native USB plus UART fallback adapter | Tooling | TBD | TBD | TBD - live sourcing required | TBD | PLANNING_ONLY | Native USB is primary; select external UART tool only if bring-up requires it

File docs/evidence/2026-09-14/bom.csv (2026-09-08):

References | Quantity | Value | Footprint | Manufacturer | MPN | Supplier | Supplier PN | Source URL | Estimated Unit Cost USD | Price Snapshot Date | Extended Estimate USD | Pricing Status | Datasheet | Notes
C1, C4 | 2 | 10uF 10V X5R | Capacitor_SMD:C_1206_3216Metric | Murata | GRM31CR61A106KA01L | LCSC | C97949 | https://www.lcsc.com/product-detail/C97949.html | 0.3352 | 2026-09-08 | 0.6704 | Dated estimate - recheck before order | https://www.murata.com/en-global/products/capacitor/mlcc/overview/lineup | Buck input bulk capacitor. | ESP32-C3 local rail bulk capacitor.
C2, C5, C7, C8, C9, C10, C11, C12, C13 | 9 | 100nF 50V X7R | Capacitor_SMD:C_0603_1608Metric | Murata | GRM188R71H104KA93D | LCSC | C77055 | https://www.lcsc.com/product-detail/C77055.html | 0.0199 | 2026-09-08 | 0.1791 | Dated estimate - recheck before order | https://www.murata.com/en-global/products/capacitor/mlcc/overview/lineup | ADS1115 local VDD bypass per datasheet. | Buck high-frequency input bypass. | ESP32-C3 high-frequency decoupling. | SHT40 local supply decoupling. | VEML7700 local supply decoupling. | Zone 1 ADC shunt filter capacitor; settling to be bench characterized. | Zone 2 ADC shunt filter capacitor; settling to be bench characterized. | Zone 3 ADC shunt filter capacitor; settling to be bench characterized. | Zone 4 ADC shunt filter capacitor; settling to be bench characterized.
C3 | 1 | 22uF 16V X5R | Capacitor_SMD:C_1206_3216Metric | Murata | GRM31CR61C226ME15L | Unassigned |  | https://www.murata.com/en-global/products/capacitor/mlcc/overview/lineup | TBD - live quote required | 2026-09-08 | TBD | Quote required | https://www.murata.com/en-global/products/capacitor/mlcc/overview/lineup | Buck output capacitor; 22 µF nominal per TI typical application.
C6 | 1 | 1uF 16V X7R | Capacitor_SMD:C_0603_1608Metric | Murata | GRM188R71C105KA12D | Unassigned |  | https://www.murata.com/en-global/products/capacitor/mlcc/overview/lineup | TBD - live quote required | 2026-09-08 | TBD | Quote required | https://www.murata.com/en-global/products/capacitor/mlcc/overview/lineup | EN power-on reset delay capacitor; bench-verify startup timing.
D1 | 1 | ESD5Z5.0T1G | Diode_SMD:D_SOD-523 | onsemi | ESD5Z5.0T1G | LCSC | C82044 | https://www.lcsc.com/product-detail/C82044.html | 0.0365 | 2026-09-08 | 0.0365 | Dated estimate - recheck before order | https://www.onsemi.com/pdf/datasheet/esd5z2.5t1-d.pdf | 5 V VBUS transient clamp after PPTC; short ground return.
F1 | 1 | 500mA hold / 1A trip | Fuse:Fuse_1812_4532Metric | Bourns | MF-MSMF050-2 | LCSC | C17313 | https://www.lcsc.com/product-detail/C17313.html | 0.0690 | 2026-09-08 | 0.0690 | Dated estimate - recheck before order | https://bourns.com/docs/product-datasheets/mf-msmf.pdf | Resettable USB input protection; bench-check radio-burst margin and nuisance trips.
J1 | 1 | USB-C POWER + NATIVE USB | Connector_USB:USB_C_Receptacle_GCT_USB4105-xx-A_16P_TopMnt_Horizontal | Global Connector Technology | USB4105-GF-A | LCSC | C3020560 | https://www.lcsc.com/product-detail/C3020560.html | 1.0319 | 2026-09-08 | 1.0319 | Dated estimate - recheck before order | https://gct.co/files/specs/usb4105-spec.pdf | USB 2.0 sink; CC1/CC2 each use 5.1 kΩ Rd; shield tied to GND.
J2 | 1 | ZONE 1 SEN0193 | Connector_JST:JST_PH_S3B-PH-K_1x03_P2.00mm_Horizontal | JST | S3B-PH-K-S(LF)(SN) | LCSC | C157929 | https://www.lcsc.com/product-detail/C157929.html | 0.0497 | 2026-09-08 | 0.0497 | Dated estimate - recheck before order | https://www.jst-mfg.com/product/pdf/eng/ePH.pdf | Zone 1: pin 1=3V3, pin 2=GND, pin 3=analog signal; verify mating cable orientation before assembly.
J3 | 1 | ZONE 2 SEN0193 | Connector_JST:JST_PH_S3B-PH-K_1x03_P2.00mm_Horizontal | JST | S3B-PH-K-S(LF)(SN) | LCSC | C157929 | https://www.lcsc.com/product-detail/C157929.html | 0.0497 | 2026-09-08 | 0.0497 | Dated estimate - recheck before order | https://www.jst-mfg.com/product/pdf/eng/ePH.pdf | Zone 2: pin 1=3V3, pin 2=GND, pin 3=analog signal; verify mating cable orientation before assembly.
J4 | 1 | ZONE 3 SEN0193 | Connector_JST:JST_PH_S3B-PH-K_1x03_P2.00mm_Horizontal | JST | S3B-PH-K-S(LF)(SN) | LCSC | C157929 | https://www.lcsc.com/product-detail/C157929.html | 0.0497 | 2026-09-08 | 0.0497 | Dated estimate - recheck before order | https://www.jst-mfg.com/product/pdf/eng/ePH.pdf | Zone 3: pin 1=3V3, pin 2=GND, pin 3=analog signal; verify mating cable orientation before assembly.
J5 | 1 | ZONE 4 SEN0193 | Connector_JST:JST_PH_S3B-PH-K_1x03_P2.00mm_Horizontal | JST | S3B-PH-K-S(LF)(SN) | LCSC | C157929 | https://www.lcsc.com/product-detail/C157929.html | 0.0497 | 2026-09-08 | 0.0497 | Dated estimate - recheck before order | https://www.jst-mfg.com/product/pdf/eng/ePH.pdf | Zone 4: pin 1=3V3, pin 2=GND, pin 3=analog signal; verify mating cable orientation before assembly.
L1 | 1 | 2.2uH 1.3A | Inductor_SMD:L_1008_2520Metric | TDK | VLS252012T-2R2M1R3 | Unassigned |  | https://product.tdk.com/en/search/inductor/inductor/smd/info?part_no=VLS252012T-2R2M1R3 | TBD - live quote required | 2026-09-08 | TBD | Quote required | https://product.tdk.com/en/search/inductor/inductor/smd/info?part_no=VLS252012T-2R2M1R3 | Datasheet-recommended TPS6216x inductor; verify saturation margin in layout/power review.
R1, R2 | 2 | 5.1k 1% | Resistor_SMD:R_0603_1608Metric | Yageo | RC0603FR-075K1L | LCSC | C105580 | https://www.lcsc.com/product-detail/C105580.html | 0.0020 | 2026-09-08 | 0.0040 | Dated estimate - recheck before order | https://www.yageo.com/upload/media/product/productsearch/datasheet/rchip/PYu-RC_Group_51_RoHS_L_16.pdf | USB-C CC1 Rd to GND. | USB-C CC2 Rd to GND.
R3 | 1 | 100k 1% | Resistor_SMD:R_0603_1608Metric | Yageo | RC0603FR-07100KL | LCSC | C14675 | https://www.lcsc.com/product-detail/C14675.html | 0.0022 | 2026-09-08 | 0.0022 | Dated estimate - recheck before order | https://www.yageo.com/upload/media/product/productsearch/datasheet/rchip/PYu-RC_Group_51_RoHS_L_16.pdf | TPS62162 open-drain PG pull-up.
R4, R5 | 2 | 4.7k 1% | Resistor_SMD:R_0603_1608Metric | Yageo | RC0603FR-074K7L | LCSC | C99782 | https://www.lcsc.com/product-detail/C99782.html | 0.0023 | 2026-09-08 | 0.0046 | Dated estimate - recheck before order | https://www.yageo.com/upload/media/product/productsearch/datasheet/rchip/PYu-RC_Group_51_RoHS_L_16.pdf | Single assembled I2C SCL pull-up to 3V3. | Single assembled I2C SDA pull-up to 3V3.
R6, R7, R8 | 3 | 10k 1% | Resistor_SMD:R_0603_1608Metric | Yageo | RC0603FR-0710KL | LCSC | C98220 | https://www.lcsc.com/product-detail/C98220.html | 0.0023 | 2026-09-08 | 0.0069 | Dated estimate - recheck before order | https://www.yageo.com/upload/media/product/productsearch/datasheet/rchip/PYu-RC_Group_51_RoHS_L_16.pdf | ADS1115 ALERT/RDY open-drain pull-up. | EN pull-up; EN must not float. | GPIO9 boot-strapping pull-up; debug header can pull low.
R9, R10, R11, R12 | 4 | 1k 1% | Resistor_SMD:R_0603_1608Metric | Yageo | RC0603FR-071KL | LCSC | C22548 | https://www.lcsc.com/product-detail/C22548.html | 0.0021 | 2026-09-08 | 0.0084 | Dated estimate - recheck before order | https://www.yageo.com/upload/media/product/productsearch/datasheet/rchip/PYu-RC_Group_51_RoHS_L_16.pdf | Zone 1 ADC series filter resistor after ESD. | Zone 2 ADC series filter resistor after ESD. | Zone 3 ADC series filter resistor after ESD. | Zone 4 ADC series filter resistor after ESD.
U1 | 1 | TPS62162DSGR 3.3V | Package_SON:WSON-8-1EP_2x2mm_P0.5mm_EP0.9x1.6mm_ThermalVias | Texas Instruments | TPS62162DSGR | LCSC | C40256 | https://www.lcsc.com/product-detail/C40256.html | 0.9697 | 2026-09-08 | 0.9697 | Dated estimate - recheck before order | https://www.ti.com/lit/ds/symlink/tps62160.pdf | Fixed 3.3 V buck; FB and exposed pad to AGND; short SW loop required.
U2 | 1 | ESP32-C3-MINI-1-H4X | pot-pulse:ESP32-C3-MINI-1 | Espressif Systems | ESP32-C3-MINI-1-H4X | LCSC | C41349510 | https://www.lcsc.com/product-detail/C41349510.html | 3.0795 | 2026-09-08 | 3.0795 | Dated estimate - recheck before order | https://www.espressif.com/sites/default/files/documentation/esp32-c3-mini-1_datasheet_en.pdf | 4 MB H4X module; native USB on GPIO18/19; antenna keepout is mandatory.
U3 | 1 | TPD4E05U06DQAR | Package_SON:USON-10_2.5x1.0mm_P0.5mm | Texas Instruments | TPD4E05U06DQAR | LCSC | C138714 | https://www.lcsc.com/product-detail/C138714.html | 0.0819 | 2026-09-05 | 0.0819 | Dated estimate - recheck before order | https://www.ti.com/lit/ds/symlink/tpd4e05u06.pdf | Four low-leakage ESD channels at probe connector boundary.
U4 | 1 | ADS1115IDGSR | Package_SO:VSSOP-10_3x3mm_P0.5mm | Texas Instruments | ADS1115IDGSR | LCSC | C37593 | https://www.lcsc.com/product-detail/C37593.html | 1.5342 | 2026-09-08 | 1.5342 | Dated estimate - recheck before order | https://www.ti.com/lit/ds/symlink/ads1115.pdf | ADDR=GND gives 0x48; four independent single-ended probe channels.
U5 | 1 | SHT40-AD1B-R2 | Sensor_Humidity:Sensirion_DFN-4_1.5x1.5mm_P0.8mm_SHT4x_NoCentralPad | Sensirion | SHT40-AD1B-R2 | LCSC | C2909890 | https://www.lcsc.com/product-detail/C2909890.html | 2.0288 | 2026-09-08 | 2.0288 | Dated estimate - recheck before order | https://sensirion.com/media/documents/33FD6951/6A7C10A0/HT_DS_Datasheet_SHT4x_V7.3.pdf | I2C 0x44; open-cavity sensor; keep away from regulator and heat sources.
U6 | 1 | VEML7700-TR | pot-pulse:VEML7700 | Vishay | VEML7700-TR | LCSC | C504893 | https://www.lcsc.com/product-detail/C504893.html | 0.7256 | 2026-09-08 | 0.7256 | Dated estimate - recheck before order | https://www.vishay.com/docs/84286/veml7700.pdf | Fixed I2C 0x10; side-view optical aperture must face enclosure opening.
U7 | 1 | USBLC6-2SC6 | Package_TO_SOT_SMD:SOT-23-6 | STMicroelectronics | USBLC6-2SC6 | LCSC | C7519 | https://www.lcsc.com/product-detail/C7519.html | 0.1639 | 2026-09-05 | 0.1639 | Dated estimate - recheck before order | https://www.st.com/resource/en/datasheet/usblc6-2.pdf | Native USB D+/D- ESD array at J1; route as a short differential pair.

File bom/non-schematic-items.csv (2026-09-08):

Item | Quantity | Manufacturer | MPN | Supplier | Source URL | Estimated Unit Cost USD | Status | Dependency | Notes
Capacitive moisture probe with PH2.0-3P cable | 4 | DFRobot | SEN0193 | DFRobot | https://www.dfrobot.com/product-1385.html | TBD - live quote required | Selected - quote required |  | Power at 3.3 V; bench-characterize output range and wet/dry repeatability; do not claim soil-water-content accuracy.
USB-C data-capable cable | 1 | TBD | TBD | Unassigned | TBD | TBD - select and quote | Pending selection | Issue #8 bring-up package | Must carry USB 2.0 data as well as power; record exact manufacturer and MPN before ordering.
Vented enclosure | 1 | TBD | TBD | Unassigned | TBD | TBD - select and quote | Blocked on mechanics | Issue #5 PCB layout | Provide SHT40 ventilation and VEML7700 optical aperture; keep metal and cable bundles outside the ESP32 antenna keepout.
Fastener and standoff set | 1 | TBD | TBD | Unassigned | TBD | TBD - select and quote | Blocked on mechanics | Issue #5 PCB layout | Select after board thickness mounting-hole pattern and enclosure stack-up are fixed.
USB-to-UART debug adapter | 1 | TBD | TBD | Unassigned | TBD | TBD - select and quote | Conditional tooling | Issue #6 firmware bring-up | Native USB is primary; purchase only if UART fallback is required and verify 3.3 V logic compatibility.

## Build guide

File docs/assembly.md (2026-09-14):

# Pot Pulse Assembly Guide (Issue #8)

## Safety and handling

- SELV-only build: USB 5 V only, no mains-connected circuitry.
- ESD controls required while handling U2/U4/U5/U6/U7.
- Do first power tests without probes inserted into soil/water.

## Required tools

- Fine-tip soldering iron + flux
- Hot-air/rework capability for fine-pitch/QFN parts
- Tweezers, magnification, solder wick
- DMM (required), optional oscilloscope
- USB serial terminal

## Inputs and references

- Board source: `hardware/kicad/pot-pulse.kicad_pcb`
- BOM source of truth: schematic symbol properties (exported to `bom/bom.csv`)
- Non-schematic procurement: `bom/non-schematic-items.csv`

## Suggested population order

1. Small passives around U1/U4/U5/U6/U7
2. U1 buck + L1 + power passives (C1/C2/C3/C4)
3. U7 USB ESD + U3 probe-line ESD
4. U4 ADS1115, U5 SHT40, U6 VEML7700
5. U2 ESP32-C3-MINI-1 module
6. Connectors J1/J2/J3/J4/J5/J6
7. Test points TP1..TP16 and mounting hardware MK1..MK3

## Orientation-critical checks

- J1 USB-C mouth flush to left board edge.
- J2–J5 latch side faces outward board edge.
- J6 notch outward for keyed ribbon orientation.
- D1 polarity band toward buck input path.
- U7 pin-1 marker orientation per footprint dot.
- U1 exposed pad soldered; avoid cold-joint voiding.

## Pre-power inspection checklist

- No solder bridges on U2/U4/U5/U6/U7 fine-pitch pins.
- Continuity check: GND plane references and no VBUS-to-GND short.
- Connector pin-1 orientation matches silk + docs.
- Rail test points TP1/TP2/TP3/TP4 physically accessible.

## First power acceptance (assembly stage)

Pass if all true:
- TP1/TP2/TP3 in expected ranges from `docs/bring-up.md`.
- No component exceeds safe touch temperature in idle state.
- USB serial `status` command responds.

Fail if any are false; do not proceed to probe calibration.

## Known release blocker carried into assembly docs

Current committed PCB DRC still has 5 unconnected items (`docs/evidence/2026-09-14/drc.json`).
This means assembled hardware is not yet fabrication-ready for production release.
The generated fabrication bundle is preview-only until DRC gate is clean.

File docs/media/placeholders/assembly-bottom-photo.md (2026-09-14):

# PLACEHOLDER — Assembly bottom photo

Status: placeholder only. Replace with a real photo from an assembled board bring-up session.

Evidence class: media placeholder (not bench evidence).

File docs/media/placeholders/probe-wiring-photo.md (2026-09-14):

# PLACEHOLDER — Probe wiring photo

Status: placeholder only. Replace with real probe/cable orientation evidence for J2–J5.

Evidence class: media placeholder (not bench evidence).

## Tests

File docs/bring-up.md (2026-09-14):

# Pot Pulse Bring-Up Guide (Issue #8)

This guide is the integration handoff for first board power-up and app/firmware validation.

> Evidence boundary: this document defines **procedure and expected checkpoints**. It is not itself bench evidence.

## 1) Pre-flight

- Use SELV USB power only (5 V).
- Do not connect wet probes during first rail checks.
- Required tools: DMM, USB-C cable, USB serial terminal, local browser, optional oscilloscope.

## 2) Wiring and pinout

```text
USB-C host
   |
   v
[J1 USB-C] -> F1 PPTC -> +5V_PROTECTED -> U1 TPS62162 -> +3V3
                                                |
                                     +----------+----------+
                                     |          |          |
                                    U2         U4         I2C sensors
                                  ESP32-C3   ADS1115      U5 SHT40 / U6 VEML7700
                                     |
                    +----------------+----------------+
                    |                |                |
                  J2 zone1         J3 zone2         J4/J5 zone3/4
```

### Zone connectors (J2–J5)

| Pin | Net | Meaning |
|---|---|---|
| 1 | +3V3 | Probe power |
| 2 | GND | Probe return |
| 3 | PROBEn_RAW | Analog moisture signal |

### Debug header (J6)

| Pin | Net |
|---|---|
| 1 | +3V3 |
| 2 | GND |
| 3 | EN |
| 4 | BOOT_GPIO9 |
| 5 | U0RXD |
| 6 | U0TXD |

## 3) First power sequence

1. Connect USB-C with no probes attached.
2. Measure rails at test pads before any functional test:
   - TP1 `VBUS`
   - TP2 `+5V_PROTECTED`
   - TP3 `+3V3`
   - TP4 `GND`
3. Confirm no unexpected heating on U1/U2/U7.
4. Open USB serial console @ 115200 and run `status`.

## 4) Expected electrical checkpoints

| Checkpoint | Expected range/state | Notes |
|---|---|---|
| TP1 VBUS | 4.75–5.25 V | USB source dependent |
| TP2 +5V_PROTECTED | close to TP1 (small PPTC drop) | Large drop indicates overcurrent path |
| TP3 +3V3 | 3.23–3.37 V target band | TPS62162 nominal 3.3 V rail |
| TP5/TP6 I2C lines | Idle HIGH near +3V3 | pull-ups R4/R5 |
| EN / BOOT pins | HIGH at idle | reset/strap sanity |

## 5) Firmware/API telemetry checkpoints

1. Pairing request (LAN): `POST /api/v1/pair/request` -> `202` with `pair_id` and `nonce`.
2. Confirm pairing over USB serial: `pair confirm <pair_id>` -> token printed only on serial.
3. Authenticated status request with `X-PotPulse-Token`:
   - `schema_version=1`
   - `time_quality` present
   - all four zones present (`z1..z4`)
   - uncalibrated zones report `quality=uncalibrated`
4. Calibrate each zone with dry/wet endpoints.
5. Verify history pagination returns bounded samples (`limit` within 1..500).

## 6) Calibration flow

Per zone:
1. Capture dry reference in air/dry medium.
2. Capture wet reference in saturated medium.
3. `POST /api/v1/calibration/zN` with `dry_raw`, `wet_raw`, thresholds.
4. Re-check `/api/v1/status` and ensure zone quality transitions from `uncalibrated` to `ok`.
5. Repeat for z1..z4.

## 7) Troubleshooting quick map

| Symptom | Probable cause | Action |
|---|---|---|
| No +3V3 at TP3 | power-path fault (J1/F1/U1/input passives) | Stop; inspect orientation and shorts |
| I2C stuck low | short or wrong pull-up/population | Isolate U4/U5/U6 branch, inspect R4/R5 |
| Pairing always 401 | missing/invalid token header | re-run pair request + serial confirm |
| Zone always uncalibrated | calibration rejected or not persisted | validate dry/wet values and retry |
| USB not enumerating | data-path/ESD path issue on DM/DP | inspect J1/U7 routing and solder joints |

## 8) Current status from static evidence

- ERC: clean (`0 errors, 0 warnings`) in `docs/evidence/2026-09-14/erc.rpt`.
- DRC: blocked for release (`5 unconnected`, plus parity warnings) in `docs/evidence/2026-09-14/drc.json`.
- Therefore this guide is a **bring-up plan**, not proof of completed bring-up.

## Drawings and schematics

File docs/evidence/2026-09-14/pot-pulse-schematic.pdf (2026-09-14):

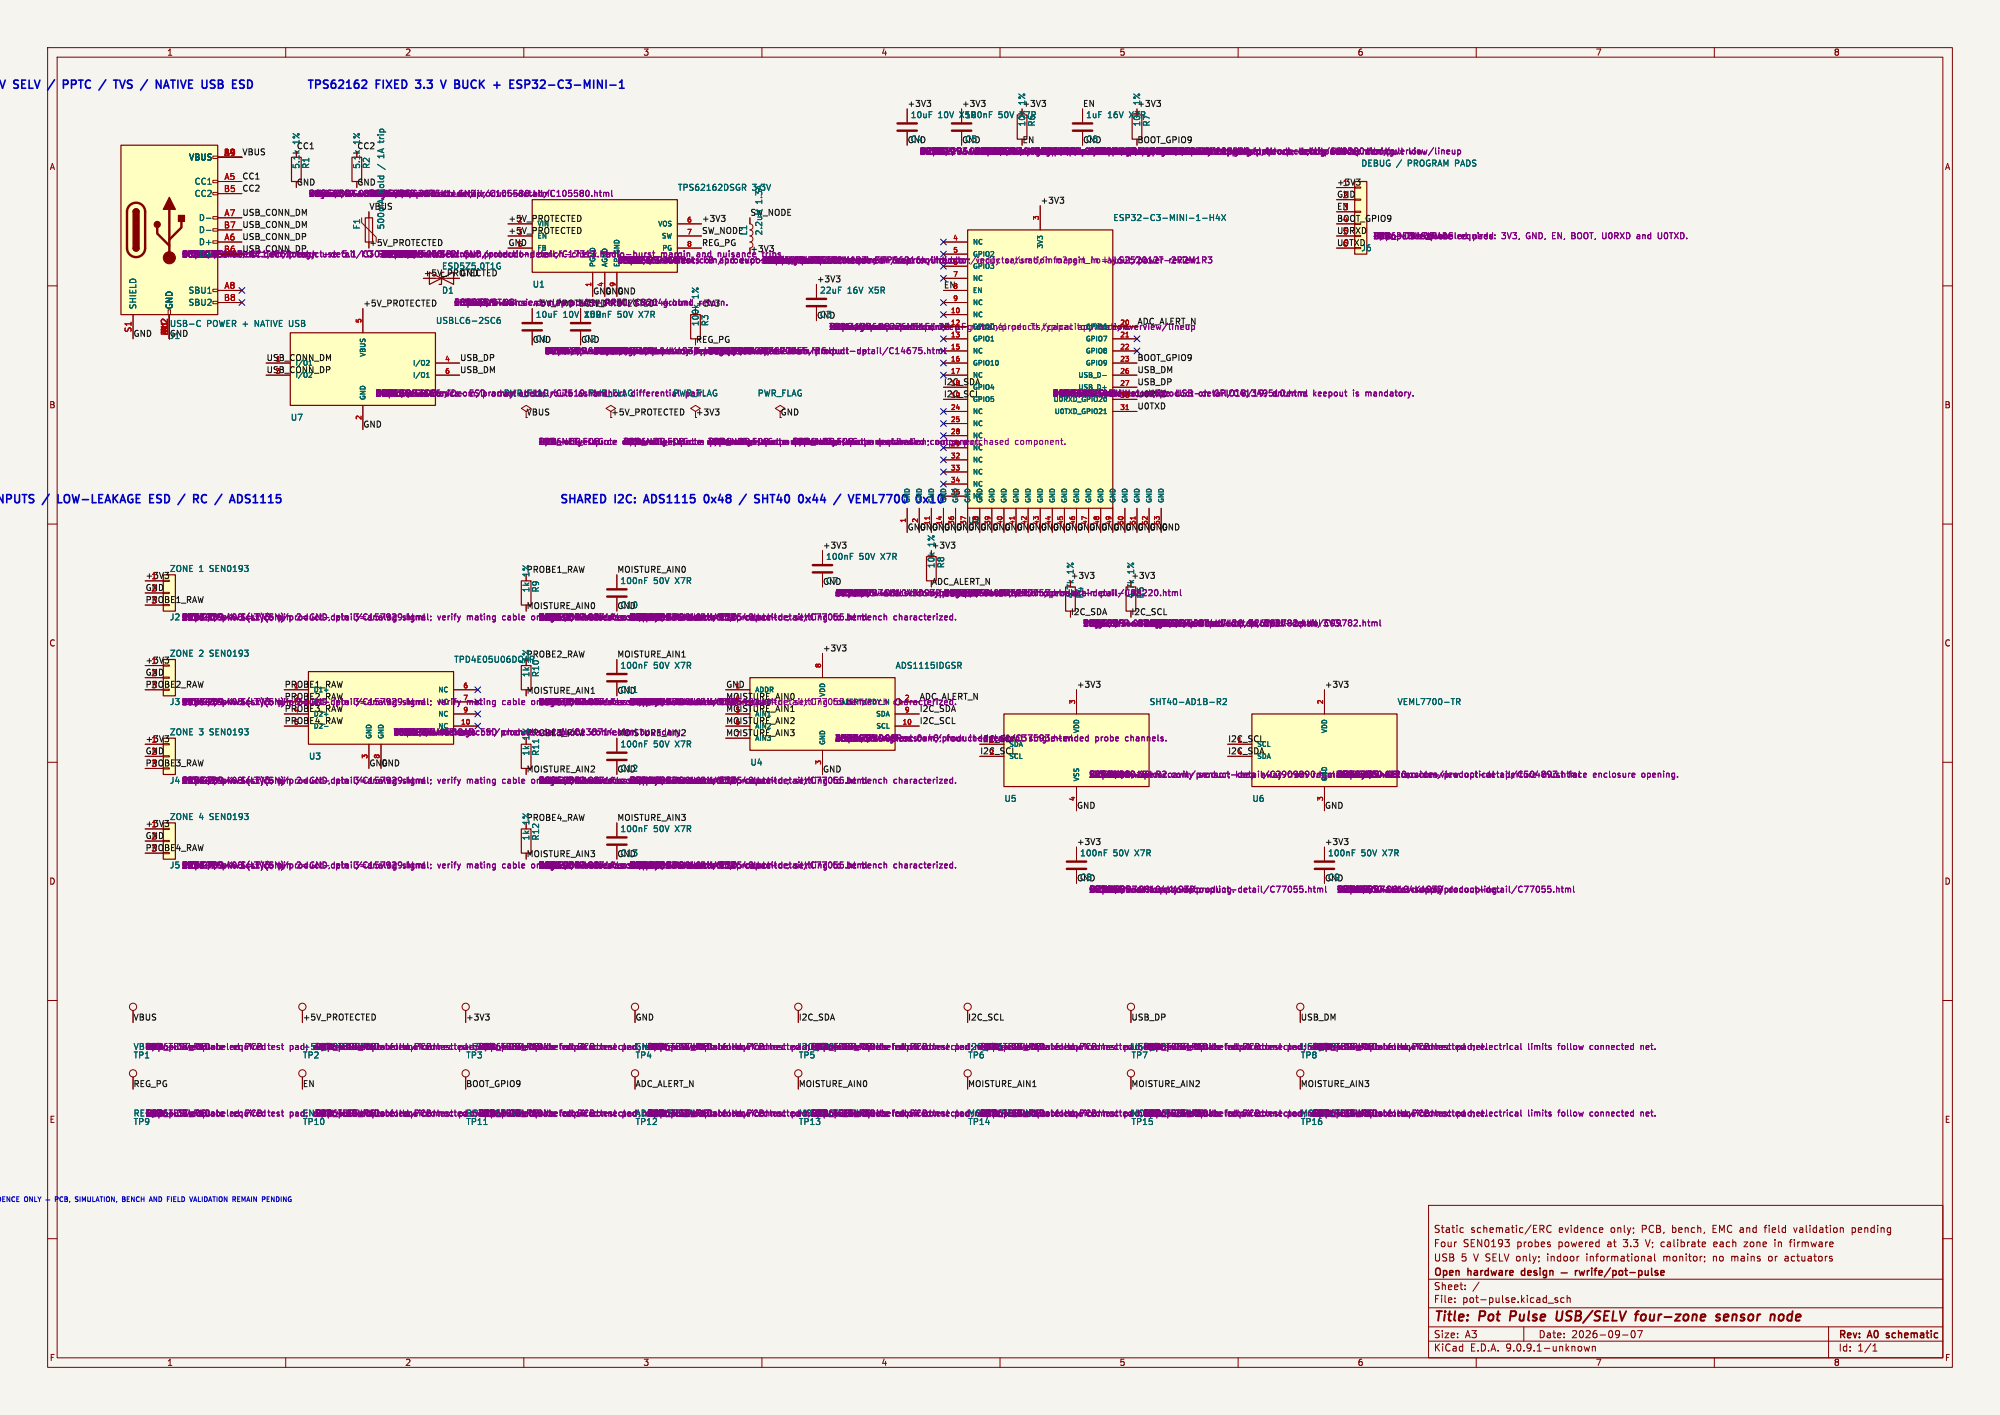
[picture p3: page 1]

RC0603FR-075K1L 0.0020 USB-C Yageo LCSC C105580 https://www.lcsc.com/product-detail/C105580.html 2026-09-08CC2 Rd to GND. 5.1k R1 1%

J6DEBUG / PROGRAM PADS
~TBD Unpopulated N/A PCB_DEBUG_PADS 2026-09-08 - live quote labledrequired pads: 3V3, GND, EN, BOOT, U0RXD and U0TXD. 1

RC0603FR-075K1L 0.0020 USB-C Yageo LCSC C105580 https://www.lcsc.com/product-detail/C105580.html 2026-09-08CC2 Rd to GND.
VBUS

3 GND 43 GND 44 GND 45 GND 46 GND 47 GND 48 GND 49 GND 50 GPIO6 20 GPIO7 21 GPIO8 22 GPIO9 23 USB_D- 26 USB_D+ 27 U0RXD_GPIO20 30 U0TXD_GPIO21 31 GND 51 GND 52 GND U2 53 ESP32-C3-MINI-1-H4X

3 GND 43 GND 44 GND 45 GND 46 GND 47 GND 48 GND 49 GND 50 GPIO6 20 GPIO7 21 GPIO8 22 GPIO9 23 USB_D- 26 USB_D+ 27 U0RXD_GPIO20 30 U0TXD_GPIO21 31 GND 51 GND 52 GND 53

2 GND 11 NC 4 GPIO2 5 GPIO3 6 NC 7 EN 8 NC 9 NC 10 GPIO0 12 GPIO1 13 NC 15 GPIO10 16 NC 17 GPIO4 18 GPIO5 19 NC 24 NC 25 NC 28 NC 29 NC 32 NC 33 NC 34 NC 35 GND 14 GND 36 GND 37 GND 38 GND 39 GND 40 GND 41 GND 42 3V3

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

TexasPS62162DSGR C40256 https://www.lcsc.com/product-detail/C40256.html 0.9697 Fixed LCSC 2026-09-08 3.3Instruments V buck; FB and exposed pad to AGND; short SW loop required. C1

+5V_PROTECTED
10uF 10V X5R Murata C97949 https://www.lcsc.com/product-detail/C97949.html 0.3352 GRM31CR61A106KA01L LCSC 2026-09-08 Buck input bulk capacitor. PWR_FLAG

3 VSS U5 4 SHT40-AD1B-R2 C2909890 https://www.lcsc.com/product-detail/C2909890.html 2.0288 Sensirion SHT40-AD1B-R2 LCSC 2026-09-08 I2C 0x44; open-cavity sensor; keep away from regulator and heat sources. C7

8 NC 6 NC 7 NC 9 NC 10 J3ZONE 2 SEN0193

100nF 50V X7R Murata GRM188R71H104KA93D C77055 https://www.lcsc.com/product-detail/C77055.html 0.0199 SHT40 LCSC 2026-09-08local supply decoupling. 1kR101%
MOISTURE_AIN1 PROBE2_RAW

8 NC 6 NC 7 NC 9 NC 10 U3 TPD4E05U06DQAR

3 TP16 MOISTURE_AIN3 PCB_TEST_PAD ~TBD Unpopulated N/A 2026-09-08 - live quote labledrequired PCB test pad; electrical limits follow connected net. TP5

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

STATIC SCHEMATIC/ERC EVIDENCE ONLY þÿ PCB, SIMULATION, BENCH AND FIELD VALIDATION REMAIN PENDING

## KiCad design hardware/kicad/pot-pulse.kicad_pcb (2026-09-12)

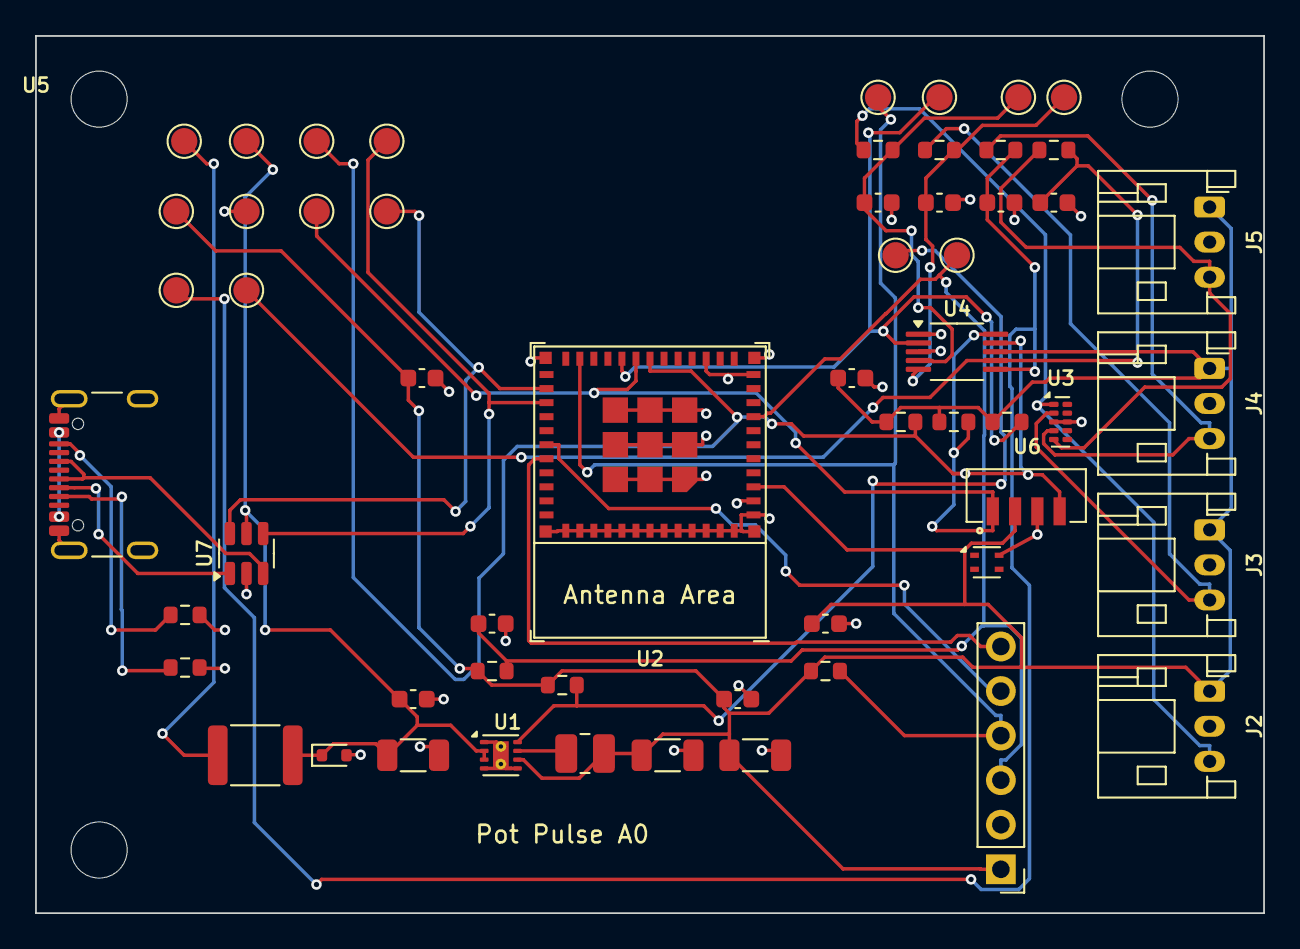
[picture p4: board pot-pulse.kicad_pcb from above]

Board: 4 copper layers, 70.0 x 50.0 mm, 60 parts (0 on the bottom side), 27 nets.

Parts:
C1, C3, C4: C_1206_3216Metric
C2, C5, C6, C7, C8, C9, C10, C11, C12, C13: C_0603_1608Metric
D1: D_SOD-523
F1: Fuse_1812_4532Metric
J1: USB_C_Receptacle_GCT_USB4105-xx-A_16P_TopMnt_Hori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; USB_C_Receptacle_GCT_USB4105-xx-A_16P_TopMnt_Horizontal
J2, J3, J4, J5: JST_PH_S3B-PH-K_1x03_P2.00mm_Horizontal
J6: PinHeader_1x06_P2.54mm_Vertical
L1: L_1008_2520Metric
MK1, MK2, MK3: MountingHole_3.2mm_M3
R1, R2, R3, R4, R5, R6, R7, R8, R9, R10, R11, R12: R_0603_1608Metric
TP1, TP2, TP3, TP4, TP5, TP6, TP7, TP8, TP9, TP10, TP11, TP12, TP13, TP14, TP15, TP16: TestPoint_Pad_D1.5mm
U1: WSON-8-1EP_2x2mm_P0.5mm_EP0.9x1.6mm_ThermalVias
U2: ESP32-C3-MINI-1
U3: USON-10_2.5x1.0mm_P0.5mm
U4: VSSOP-10_3x3mm_P0.5mm
U5: Sensirion_DFN-4_1.5x1.5mm_P0.8mm_SHT4x_NoCentralP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; Sensirion_DFN-4_1.5x1.5mm_P0.8mm_SHT4x_NoCentralPad
U6: VEML7700
U7: SOT-23-6

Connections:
/+3V3: C3.1, C4.1, C5.1, C7.1, C8.1, C9.1, J2.1, J3.1, J4.1, J5.1, J6.1, L1.2, R3.1, R4.1, R5.1, R6.1, R7.1, R8.1, TP3.1, U1.6, U2.3, U4.8, U5.3, U6.2
/+5V_PROTECTED: C1.1, C2.1, D1.1, F1.2, TP2.1, U1.2, U1.3, U7.5
/ADC_ALERT_N: R8.2, TP12.1, U2.20, U4.2
/BOOT_GPIO9: J6.4, R7.2, TP11.1, U2.23
/CC1: J1.A5, R1.1
/CC2: J1.B5, R2.1
/EN: C6.1, J6.3, R6.2, TP10.1, U2.8
/GND: C1.2, C2.2, C3.2, C4.2, C5.2, C6.2, C7.2, C8.2, C9.2, C10.2, C11.2, C12.2, C13.2, D1.2, J1.A1, J1.A12, J1.B1, J1.B12, J1.S1, J2.2, J3.2, J4.2, J5.2, J6.2, R1.2, R2.2, TP4.1, U1.1, U1.4, U1.5, U1.9, U2.1, U2.2, U2.11, U2.14, U2.36, U2.37, U2.38, U2.39, U2.40, U2.41, U2.42, U2.43, U2.44, U2.45, U2.46, U2.47, U2.48, U2.49, U2.50, U2.51, U2.52, U2.53, U3.3, U3.8, U4.1, U4.3, U5.4, U6.3, U7.2
/I2C_SCL: R5.2, TP6.1, U2.19, U4.10, U5.2, U6.1
/I2C_SDA: R4.2, TP5.1, U2.18, U4.9, U5.1, U6.4
/MOISTURE_AIN0: C10.1, R9.2, TP13.1, U4.4
/MOISTURE_AIN1: C11.1, R10.2, TP14.1, U4.5
/MOISTURE_AIN2: C12.1, R11.2, TP15.1, U4.6
/MOISTURE_AIN3: C13.1, R12.2, TP16.1, U4.7
/PROBE1_RAW: J2.3, R9.1, U3.1
/PROBE2_RAW: J3.3, R10.1, U3.2
/PROBE3_RAW: J4.3, R11.1, U3.4
/PROBE4_RAW: J5.3, R12.1, U3.5
/REG_PG: R3.2, TP9.1, U1.8
/SW_NODE: L1.1, U1.7
/U0RXD: J6.5, U2.30
/U0TXD: J6.6, U2.31
/USB_CONN_DM: J1.A7, J1.B7, U7.1
/USB_CONN_DP: J1.A6, J1.B6, U7.3
/USB_DM: TP8.1, U2.26, U7.6
/USB_DP: TP7.1, U2.27, U7.4
/VBUS: F1.1, J1.A4, J1.A9, J1.B4, J1.B9, TP1.1

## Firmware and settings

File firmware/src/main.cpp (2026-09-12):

// Pot Pulse device firmware — ESP32-C3 (ESP32-C3-MINI-1 on the pot-pulse
// carrier, issue #5). Thin device layer over the portable core:
//   - GPIO/I2C pin map matches hardware/kicad netlist (issue #3).
//   - Web server endpoints freeze the docs/protocol.md contract (§ issue #6).
//   - USB serial (native USB CDC) provides provisioning + recovery without
//     Wi-Fi or cloud (IF-DBG-01).
//
// Evidence boundary: compiles and links for the device target; behavior is
// verified by native unit tests of the portable core. No bench/field claim.
#if !defined(PP_NATIVE_TEST)

#include <ArduinoJson.h>
#include <LittleFS.h>
#include <Preferences.h>
#include <WiFi.h>
#include <WebServer.h>
#include <Wire.h>

#include <sys/time.h>

#include <cstdlib>
#include <tuple>
#include <vector>

#include "pp/calibration.h"
#include "pp/config.h"
#include "pp/history.h"
#include "pp/pipeline.h"
#include "pp/sensors.h"

// ---- board mapping (hardware/kicad/schematic-notes.md §Interfaces) ----
static constexpr int PIN_I2C_SDA = 4;   // GPIO4  / I2C_SDA
static constexpr int PIN_I2C_SCL = 5;   // GPIO5  / I2C_SCL
static constexpr int PIN_ADC_ALERT = 6;  // GPIO6 / ADC_ALERT_N (monitored)

// Calibration persistence (defined below; used by HTTP handlers above).
static void save_calibration();
static void clear_calibration_store();

// ---- device HAL adapters ----

class WireI2c : public pp::II2c {
  public:
    bool write_read(uint8_t addr, const uint8_t* wr, size_t wr_len, uint8_t* rd,
                    size_t rd_len) override {
        Wire.setTimeOut(20);  // bounded bus timeout (R-04)
        Wire.beginTransmission(addr);
        for (size_t i = 0; i < wr_len; i++) Wire.write(wr[i]);
        if (Wire.endTransmission(true) != 0) return false;
        if (rd_len == 0) return true;
        const size_t got = Wire.requestFrom(addr, (uint8_t)rd_len);
        if (got != rd_len) return false;
        for (size_t i = 0; i < rd_len; i++) rd[i] = Wire.read();
        return true;
    }
};

class EspClock : public pp::IClock {
  public:
    uint64_t monotonic_ms() const override { return millis(); }
    int64_t wall_ms() const override {
        struct timeval tv;
        gettimeofday(&tv, nullptr);
        // SNTP sets the system clock; before sync it stays at the 1970 epoch.
        if (tv.tv_sec < 1600000000) return -1;  // pre-2020 = unsynchronized
        return int64_t(tv.tv_sec) * 1000 + tv.tv_usec / 1000;
    }
};

class EspSecrets : public pp::ISecrets {
  public:
    std::string device_id() const override {
        uint64_t mac = ESP.getEfuseMac();
        char buf[20];
        snprintf(buf, sizeof(buf), "potpulse-%04X",
                 uint16_t(mac & 0xFFFF));
        return std::string(buf);
    }
    void random_bytes(uint8_t* out, size_t n) override {
        esp_fill_random(out, n);
    }
};

class PrefKv : public pp::IKv {
  public:
    std::string get(const std::string& key,
                    const std::string& fallback) const override {
        ensure_open();
        return std::string(
            prefs_.getString(key.c_str(), fallback.c_str()).c_str());
    }
    void put(const std::string& key, const std::string& value) override {
        ensure_open();
        prefs_.putString(key.c_str(), value.c_str());
    }
    void remove(const std::string& key) override {
        ensure_open();
        prefs_.remove(key.c_str());
    }

  private:
    mutable Preferences prefs_;
    mutable bool opened = false;
    void ensure_open() const {
        if (!opened) {
            prefs_.begin("potpulse", false);
            opened = true;
        }
    }
};

// ---- globals ----

static WireI2c g_i2c;
static EspClock g_clock;
static EspSecrets g_secrets;
static PrefKv g_kv;
static pp::ConfigStore g_config(&g_kv, &g_secrets, &g_clock);
static pp::CalibrationStore g_cal;
static pp::History g_history;
static pp::Ads1115 g_adc(&g_i2c);
static pp::Sht40 g_sht(&g_i2c);
static pp::Veml7700 g_veml(&g_i2c);
static pp::Sampler g_sampler(&g_adc, &g_sht, &g_veml, &g_cal, &g_history,
                             &g_clock);
static pp::Environment g_env;
static pp::MoistureSample g_zones[pp::kZoneCount];
static WebServer g_server(80);
static uint32_t g_last_sample_ms = 0;
static bool g_pending_restore_applies = false;

// ---- helpers ----

static bool authorized() {
    return g_server.hasHeader("X-PotPulse-Token") &&
           g_config.authorize(g_server.header("X-PotPulse-Token").c_str());
}

static void send_json(int code, const std::string& body) {
    g_server.send(code, "application/json", body.c_str());
}

static void require_auth_or_401() {
    if (!authorized()) {
        send_json(401, pp::render_error_json("unauthorized",
                                             "valid pairing token required"));
    }
}

static bool parse_zone_id(const String& s, int* out) {
    return pp::zone_index_of(s.c_str(), out);
}

static pp::StatusSnapshot snapshot() {
    pp::StatusSnapshot snap;
    snap.env = g_env;
    for (int z = 0; z < pp::kZoneCount; z++) snap.zones[z] = g_zones[z];
    snap.time_quality = g_sampler.time_quality();
    snap.wall_ms = g_clock.wall_ms();
    snap.paired = g_config.paired();
    snap.device_id = g_secrets.device_id();
    return snap;
}

// ---- endpoints ----

// GET /api/v1/status — pre-pairing first-run status contains NO device_id,
// no user zone names, and no retained history (protocol security boundary).
static void handle_status() {
    pp::StatusSnapshot snap = snapshot();
    if (!authorized()) {
        snap.device_id.clear();  // stable tracking id withheld pre-pairing
    }
    send_json(200, pp::render_status_json(snap));
}

// GET /api/v1/history?zone=<id>&from=<ts>&to=<ts>&limit=<n> — protected:
// returns retained user history (protocol state-changing/user-data list).
static void handle_history() {
    require_auth_or_401();
    if (g_server.arg("zone").length() == 0) {
        send_json(400, pp::render_error_json("bad_request", "zone required"));
        return;
    }
    int zone_idx = -1;
    if (!parse_zone_id(g_server.arg("zone"), &zone_idx)) {
        send_json(400, pp::render_error_json("bad_request", "zone unknown"));
        return;
    }
    int limit = g_server.arg("limit").length() ? g_server.arg("limit").toInt()
                                               : 100;
    if (limit < 1 || limit > 500) {
        send_json(400, pp::render_error_json("bad_request", "limit range"));
        return;
    }
    auto page = g_history.page(pp::zone_id(zone_idx),
                               atoll(g_server.arg("from").c_str()),
                               atoll(g_server.arg("to").c_str()), limit);
    send_json(200, pp::render_history_json(page, pp::zone_id(zone_idx)));
}

// POST /api/v1/pair/request — open on LAN, no user data; single active
// request; confirmation is out-of-band over USB serial (fail closed).
static void handle_pair_request() {
    pp::PairRequest req;
    if (!g_config.create_pair_request(&req)) {
        send_json(409, pp::render_error_json(
                           "request_active", "one active pairing request"));
        return;
    }
    JsonDocument doc;
    doc["pair_id"] = req.pair_id;
    doc["nonce"] = req.nonce;
    doc["confirm_over"] = "usb-serial";
    std::string out;
    serializeJson(doc, out);
    send_json(202, out);
}

// POST /api/v1/calibration/<zone_id> {dry_raw, wet_raw, dry_threshold,
// wet_threshold}
static void handle_calibration(const String& zone_id) {
    require_auth_or_401();
    if (!g_server.hasArg("plainBody")) return;
    JsonDocument doc;
    if (deserializeJson(doc, g_server.arg("plainBody"))) {
        send_json(400, pp::render_error_json("bad_json", "malformed body"));
        return;
    }
    uint8_t zone = 0;
    int zone_idx = -1;
    if (!parse_zone_id(zone_id, &zone_idx)) {
        send_json(400, pp::render_error_json("bad_request", "zone unknown"));
        return;
    }
    zone = uint8_t(zone_idx);
    if (!doc["dry_raw"].is<int32_t>() || !doc["wet_raw"].is<int32_t>()) {
        send_json(400, pp::render_error_json("bad_request",
                                             "dry_raw/wet_raw required"));
        return;
    }
    const float dt = doc["dry_threshold"] | 0.30f;
    const float wt = doc["wet_threshold"] | 0.70f;
    if (!g_cal.set(zone, doc["dry_raw"], doc["wet_raw"], dt, wt)) {
        send_json(400, pp::render_error_json("bad_request",
                                             "endpoints/thresholds invalid"));
        return;
    }
    save_calibration();
    g_sampler.sample_once(&g_env, g_zones);  // reflect immediately
    send_json(200, pp::render_ok_json("calibration_stored"));
}

// POST /api/v1/config {sample_interval_ms?, zone_names?[]}
static void handle_config() {
    require_auth_or_401();
    JsonDocument doc;
    if (deserializeJson(doc, g_server.arg("plainBody"))) {
        send_json(400, pp::render_error_json("bad_json", "malformed body"));
        return;
    }
    std::vector<std::string> applied;
    if (doc["sample_interval_ms"].is<uint32_t>()) {
        if (!g_config.set_sample_interval_ms(doc["sample_interval_ms"])) {
            send_json(400, pp::render_error_json(
                               "bad_request", "interval out of range"));
            return;
        }
        applied.push_back("sample_interval_ms");
    }
    if (JsonArray names = doc["zone_names"].as<JsonArray>()) {
        int z = 0;
        for (JsonVariant n : names) {
            if (z >= pp::kZoneCount) break;
            const char* s = n.as<const char*>();
            if (!s || !g_config.set_zone_name(uint8_t(z), s)) {
                send_json(400, pp::render_error_json("bad_request",
                                                     "zone name invalid"));
                return;
            }
            z++;
        }
        applied.push_back("zone_names");
    }
    JsonDocument out;
    out["ok"] = true;
    JsonArray arr = out["applied"].to<JsonArray>();
    for (auto& a : applied) arr.add(a);
    std::string body;
    serializeJson(out, body);
    send_json(200, body);
}

// POST /api/v1/export — canonical versioned export; no secrets (R-09).
static void handle_export() {
    require_auth_or_401();
    send_json(200, pp::render_export_json(g_secrets.device_id(), g_history,
                                          g_config));
}

// POST /api/v1/backup — settings + calibration + zone metadata (protocol:
// credentials/samples excluded).
static void handle_backup() {
    require_auth_or_401();
    JsonDocument doc;
    doc["backup_version"] = 1;
    doc["sample_interval_ms"] = g_config.settings().sample_interval_ms;
    JsonArray names = doc["zone_names"].to<JsonArray>();
    for (int z = 0; z < pp::kZoneCount; z++) {
        names.add(g_config.settings().zone_names[z]);
    }
    JsonArray cals = doc["calibrations"].to<JsonArray>();
    for (auto& [zone, cal] : g_cal.list()) {
        JsonObject c = cals.add<JsonObject>();
        c["zone_id"] = zone;
        c["dry_raw"] = cal.dry_raw;
        c["wet_raw"] = cal.wet_raw;
        c["dry_threshold"] = cal.dry_threshold;
        c["wet_threshold"] = cal.wet_threshold;
    }
    std::string out;
    serializeJson(doc, out);
    send_json(200, out);
}

// POST /api/v1/restore — validate complete payload BEFORE mutation
// (protocol: atomic or not at all).
static void handle_restore() {
    require_auth_or_401();
    JsonDocument doc;
    if (deserializeJson(doc, g_server.arg("plainBody"))) {
        send_json(400, pp::render_error_json("bad_json", "malformed body"));
        return;
    }
    if (doc["backup_version"] != 1) {
        send_json(422, pp::render_error_json("incompatible_version",
                                             "only backup_version 1 accepted"));
        return;
    }
    // Validate everything first.
    const uint32_t interval =
        doc["sample_interval_ms"] | g_config.settings().sample_interval_ms;
    if (interval < pp::kMinSampleIntervalMs ||
        interval > pp::kMaxSampleIntervalMs) {
        send_json(400, pp::render_error_json("bad_request",
                                             "interval out of range"));
        return;
    }
    std::vector<std::tuple<int, int32_t, int32_t, float, float>> cals;
    for (JsonObject c : doc["calibrations"].as<JsonArray>()) {
        const long zone = c["zone_id"] | -1;
        if (zone < 0 || zone >= pp::kZoneCount || !c["dry_raw"].is<int32_t>() ||
            !c["wet_raw"].is<int32_t>() ||
            c["dry_raw"].as<int32_t>() == c["wet_raw"].as<int32_t>()) {
            send_json(400, pp::render_error_json("bad_request",
                                                 "calibration invalid"));
            return;  // nothing mutated above
        }
        cals.emplace_back(int(zone), c["dry_raw"], c["wet_raw"],
                          c["dry_threshold"] | 0.30f,
                          c["wet_threshold"] | 0.70f);
    }
    // All valid — apply.
    g_config.set_sample_interval_ms(interval);
    int z = 0;
    for (JsonVariant n : doc["zone_names"].as<JsonArray>()) {
        if (z >= pp::kZoneCount) break;
        const char* s = n.as<const char*>();
        if (s) g_config.set_zone_name(uint8_t(z), s);
        z++;
    }
    for (auto& [zone, dr, wr, dt, wt] : cals) {
        g_cal.set(uint8_t(zone), dr, wr, dt, wt);
    }
    save_calibration();
    send_json(200, pp::render_ok_json("restore_applied"));
}

// DELETE /api/v1/history?confirm=confirm
static void handle_history_delete() {
    require_auth_or_401();
    if (g_server.arg("confirm") != pp::ConfigStore::kConfirmWord) {
        send_json(428, pp::render_error_json(
                           "confirmation_required",
                           "append ?confirm=confirm to delete retained history"));
        return;
    }
    const int deleted = g_history.clear();
    JsonDocument doc;
    doc["ok"] = true;
    doc["deleted"] = deleted;
    doc["complete"] = (g_history.size() == 0);
    std::string out;
    serializeJson(doc, out);
    send_json(200, out);
}

// POST /api/v1/reset {level:"full-firmware", confirm:"confirm"}
// full-firmware erases: pairing tokens, settings, zone metadata,
// calibration, retained history. Network (Wi-Fi) credentials are RETAINED
// so the device stays reachable; documented below and in firmware/README.
static void handle_reset() {
    require_auth_or_401();
    JsonDocument doc;
    if (deserializeJson(doc, g_server.arg("plainBody"))) {
        send_json(400, pp::render_error_json("bad_json", "malformed body"));
        return;
    }
    if (doc["confirm"] != pp::ConfigStore::kConfirmWord ||
        doc["level"] != "full-firmware") {
        send_json(400, pp::render_error_json(
                           "bad_request",
                           "requires {level:'full-firmware',confirm:'confirm'}"));
        return;
    }
    g_config.reset_all();
    clear_calibration_store();
    g_history.clear();
    send_json(200, pp::render_ok_json("factory_reset"));
    delay(200);
    ESP.restart();
}

// ---- calibration persistence on flash ----

static const char* kCalPath = "/calibration.json";

static void save_calibration() {
    JsonDocument doc;
    JsonArray cals = doc.to<JsonArray>();
    for (auto& [zone, cal] : g_cal.list()) {
        JsonObject c = cals.add<JsonObject>();
        c["zone_id"] = zone;
        c["dry_raw"] = cal.dry_raw;
        c["wet_raw"] = cal.wet_raw;
        c["dry_threshold"] = cal.dry_threshold;
        c["wet_threshold"] = cal.wet_threshold;
    }
    File f = LittleFS.open(kCalPath, "w");
    if (f) {
        serializeJson(doc, f);
        f.close();
    }
}

static void load_calibration() {
    File f = LittleFS.open(kCalPath, "r");
    if (!f) return;
    JsonDocument doc;
    if (!deserializeJson(doc, f)) {
        for (JsonObject c : doc.as<JsonArray>()) {
            const long zone = c["zone_id"] | -1;
            if (zone >= 0 && zone < pp::kZoneCount &&
                c["dry_raw"].is<int32_t>() && c["wet_raw"].is<int32_t>()) {
                g_cal.set(uint8_t(zone), c["dry_raw"], c["wet_raw"],
                          c["dry_threshold"] | 0.30f,
                          c["wet_threshold"] | 0.70f);
            }
        }
    }
    f.close();
}

static void clear_calibration_store() {
    for (auto& [zone, _] : g_cal.list()) g_cal.clear(uint8_t(zone));
    LittleFS.remove(kCalPath);
}

// ---- USB serial console: provisioning, pairing confirm, recovery ----
// Available over native USB CDC with no Wi-Fi or cloud dependency.

static void serial_service() {
    static String line;
    while (Serial.available()) {
        const char c = char(Serial.read());
        if (c != '\n' && c != '\r') line += c;
        else if (line.length()) {
            line.trim();
            if (line == "status") {
                Serial.printf("fw pot-pulse 0.1.0 time=%s paired=%d "
                              "history=%d/%d interval_ms=%u\n",
                              pp::time_quality_str(g_sampler.time_quality()),
                              g_config.paired() ? 1 : 0, g_history.size(),
                              g_history.capacity(),
                              g_config.settings().sample_interval_ms);
            } else if (line == "pair list") {
                for (const auto& t : g_config.tokens()) {
                    Serial.printf("token %s… label=%s\n",
                                  t.token.substr(0, 4).c_str(), t.label.c_str());
                }
                if (g_config.pending_request().active) {
                    Serial.printf("pending pair_id=%s nonce=%s\n",
                                  g_config.pending_request().pair_id.c_str(),
                                  g_config.pending_request().nonce.c_str());
                }
            } else if (line.startsWith("pair confirm ")) {
                const std::string pair_id =
                    line.substring(13).c_str();
                pp::PairingToken t;
                if (g_config.confirm_pair_request(pair_id, &t)) {
                    // Token displayed ONLY on the local USB console (out-of-
                    // band confirmation channel, R-06).
                    Serial.printf("token %s\n", t.token.c_str());
                } else {
                    Serial.println("no pending request with that pair_id");
                }
            } else if (line.startsWith("wifi ")) {
                const int sp = line.indexOf(' ', 5);
                if (sp < 0) {
                    Serial.println("usage: wifi <ssid> <password>");
                } else {
                    WiFi.begin(line.substring(5, sp).c_str(),
                               line.substring(sp + 1).c_str());
                    Serial.println("wifi connecting (state preserved by SDK)");
                }
            } else if (line == "reset wifi") {
                WiFi.disconnect(true);
                Serial.println("wifi credentials erased");
            } else if (line == "reset full-firmware") {
                g_config.reset_all();
                clear_calibration_store();
                g_history.clear();
                Serial.println("factory reset complete; restarting");
                delay(200);
                ESP.restart();
            } else if (line == "help") {
                Serial.println("commands: status | pair list | pair confirm "
                               "<pair_id> | wifi <ssid> <pass> | reset wifi | "
                               "reset full-firmware");
            } else {
                Serial.println("unknown command; try 'help'");
            }
            line = "";
        }
    }
}

// ---- Arduino entrypoints ----

void setup() {
    Serial.begin(115200);  // native USB CDC (GPIO18/19 via USBLC6-2SC6)

    Wire.begin(PIN_I2C_SDA, PIN_I2C_SCL);
    Wire.setClock(100000);  // standard mode (bus spec §component-selection)

    if (!LittleFS.begin(true)) {
        Serial.println("LittleFS mount failed; calibration will not persist");
    }
    load_calibration();

    pinMode(PIN_ADC_ALERT, INPUT_PULLUP);  // ADS1115 ALERT/RDY monitor

    g_adc.begin();
    g_veml.begin();
    g_sampler.sample_once(&g_env, g_zones);  // first readings before serving

    if (WiFi.psk()) {
        WiFi.begin();
        configTime(0, 0, "pool.ntp.org");  // time only; no cloud dependency
    }

    g_server.on("/api/v1/status", HTTP_GET, handle_status);
    g_server.on("/api/v1/history", HTTP_GET, handle_history);
    g_server.on("/api/v1/history", HTTP_DELETE, handle_history_delete);
    g_server.on("/api/v1/pair/request", HTTP_POST, handle_pair_request);
    g_server.on("/api/v1/calibration/z1", HTTP_POST,
                [] { handle_calibration("z1"); });
    g_server.on("/api/v1/calibration/z2", HTTP_POST,
                [] { handle_calibration("z2"); });
    g_server.on("/api/v1/calibration/z3", HTTP_POST,
                [] { handle_calibration("z3"); });
    g_server.on("/api/v1/calibration/z4", HTTP_POST,
                [] { handle_calibration("z4"); });
    g_server.on("/api/v1/config", HTTP_POST, handle_config);
    g_server.on("/api/v1/export", HTTP_POST, handle_export);
    g_server.on("/api/v1/backup", HTTP_POST, handle_backup);
    g_server.on("/api/v1/restore", HTTP_POST, handle_restore);
    g_server.on("/api/v1/reset", HTTP_POST, handle_reset);
    g_server.begin();

    g_last_sample_ms = millis();
    Serial.println("pot-pulse firmware ready");
}

void loop() {
    g_server.handleClient();
    serial_service();
    if (millis() - g_last_sample_ms >=
        g_config.settings().sample_interval_ms) {
        g_sampler.sample_once(&g_env, g_zones);
        g_last_sample_ms = millis();
    }
}

#endif  // !PP_NATIVE_TEST

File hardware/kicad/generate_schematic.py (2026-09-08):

#!/usr/bin/env python3
"""Generate the editable Pot Pulse first-pass schematic.

Manufacturer datasheets cited in hardware/component-selection.md are the
pinout/electrical source of truth.  The generated KiCad schematic remains
editable; this script only makes the first capture reproducible.
"""
from __future__ import annotations

import argparse
import os
import re
from pathlib import Path

RES_DS = "https://www.yageo.com/upload/media/product/productsearch/datasheet/rchip/PYu-RC_Group_51_RoHS_L_16.pdf"
CAP_DS = "https://www.murata.com/en-global/products/capacitor/mlcc/overview/lineup"
PRICE_SNAPSHOT_DATE = "2026-09-08"

# Exact source records queried by MPN on PRICE_SNAPSHOT_DATE. USBLC6-2SC6
# and TPD4E05U06DQAR intentionally retain the manufacturer-validated LCSC
# records from the 2026-09-05 component-selection snapshot; newer same-MPN
# search hits did not expose manufacturer identity and are not substitutions.
SOURCING: dict[str, tuple[str, str, str, str, str]] = {
    # MPN: (supplier, supplier PN, source URL, estimated unit cost USD, snapshot date)
    "ADS1115IDGSR": ("LCSC", "C37593", "https://www.lcsc.com/product-detail/C37593.html", "1.5342", PRICE_SNAPSHOT_DATE),
    "ESD5Z5.0T1G": ("LCSC", "C82044", "https://www.lcsc.com/product-detail/C82044.html", "0.0365", PRICE_SNAPSHOT_DATE),
    "ESP32-C3-MINI-1-H4X": ("LCSC", "C41349510", "https://www.lcsc.com/product-detail/C41349510.html", "3.0795", PRICE_SNAPSHOT_DATE),
    "GRM188R71H104KA93D": ("LCSC", "C77055", "https://www.lcsc.com/product-detail/C77055.html", "0.0199", PRICE_SNAPSHOT_DATE),
    "GRM31CR61A106KA01L": ("LCSC", "C97949", "https://www.lcsc.com/product-detail/C97949.html", "0.3352", PRICE_SNAPSHOT_DATE),
    "MF-MSMF050-2": ("LCSC", "C17313", "https://www.lcsc.com/product-detail/C17313.html", "0.0690", PRICE_SNAPSHOT_DATE),
    "RC0603FR-07100KL": ("LCSC", "C14675", "https://www.lcsc.com/product-detail/C14675.html", "0.0022", PRICE_SNAPSHOT_DATE),
    "RC0603FR-0710KL": ("LCSC", "C98220", "https://www.lcsc.com/product-detail/C98220.html", "0.0023", PRICE_SNAPSHOT_DATE),
    "RC0603FR-071KL": ("LCSC", "C22548", "https://www.lcsc.com/product-detail/C22548.html", "0.0021", PRICE_SNAPSHOT_DATE),
    "RC0603FR-074K7L": ("LCSC", "C99782", "https://www.lcsc.com/product-detail/C99782.html", "0.0023", PRICE_SNAPSHOT_DATE),
    "RC0603FR-075K1L": ("LCSC", "C105580", "https://www.lcsc.com/product-detail/C105580.html", "0.0020", PRICE_SNAPSHOT_DATE),
    "S3B-PH-K-S(LF)(SN)": ("LCSC", "C157929", "https://www.lcsc.com/product-detail/C157929.html", "0.0497", PRICE_SNAPSHOT_DATE),
    "SHT40-AD1B-R2": ("LCSC", "C2909890", "https://www.lcsc.com/product-detail/C2909890.html", "2.0288", PRICE_SNAPSHOT_DATE),
    "TPD4E05U06DQAR": ("LCSC", "C138714", "https://www.lcsc.com/product-detail/C138714.html", "0.0819", "2026-09-05"),
    "TPS62162DSGR": ("LCSC", "C40256", "https://www.lcsc.com/product-detail/C40256.html", "0.9697", PRICE_SNAPSHOT_DATE),
    "USB4105-GF-A": ("LCSC", "C3020560", "https://www.lcsc.com/product-detail/C3020560.html", "1.0319", PRICE_SNAPSHOT_DATE),
    "USBLC6-2SC6": ("LCSC", "C7519", "https://www.lcsc.com/product-detail/C7519.html", "0.1639", "2026-09-05"),
    "VEML7700-TR": ("LCSC", "C504893", "https://www.lcsc.com/product-detail/C504893.html", "0.7256", PRICE_SNAPSHOT_DATE),
}


def find_symbol_dir(explicit: str | None) -> Path:
    for candidate in (explicit, os.environ.get("KICAD_SYMBOL_DIR"), "/usr/share/kicad/symbols"):
        if candidate and Path(candidate).is_dir():
            return Path(candidate)
    raise SystemExit("KiCad symbol libraries not found; pass --symbol-dir")


def q(value: str) -> str:
    return value.replace("\\", "\\\\").replace('"', '\\"')


def custom_symbol(name: str, ref: str, footprint: str, datasheet: str,
                  description: str, pins: list[tuple[str, str, str, str]]) -> str:
    sides = {side: [p for p in pins if p[3] == side] for side in "LRTB"}
    rows = max(len(sides["L"]), len(sides["R"]), 4)
    half_h = max(7.62, (rows + 1) * 1.27)
    half_w = 15.24
    out = [
        f'  (symbol "{q(name)}" (pin_names (offset 1.016)) (in_bom yes) (on_board yes)',
        f'    (property "Reference" "{q(ref)}" (at {-half_w} {half_h + 2.54} 0) (effects (font (size 1.27 1.27)) (justify left bottom)))',
        f'    (property "Value" "{q(name)}" (at {half_w} {-half_h - 2.54} 0) (effects (font (size 1.27 1.27)) (justify right top)))',
        f'    (property "Footprint" "{q(footprint)}" (at 0 {-half_h - 5.08} 0) (effects (font (size 1.27 1.27)) hide))',
        f'    (property "Datasheet" "{q(datasheet)}" (at 0 {-half_h - 7.62} 0) (effects (font (size 1.27 1.27)) hide))',
        f'    (property "ki_description" "{q(description)}" (at 0 0 0) (effects (font (size 1.27 1.27)) hide))',
        f'    (symbol "{q(name)}_0_1" (rectangle (start {-half_w} {half_h}) (end {half_w} {-half_h}) (stroke (width 0.254) (type default)) (fill (type background))))',
        f'    (symbol "{q(name)}_1_1"',
    ]

    def pin_line(pin: tuple[str, str, str, str], idx: int, count: int) -> str:
        number, pname, ptype, side = pin
        if side == "L":
            x, y, angle = -half_w - 5.08, (count - 1 - 2 * idx) * 1.27, 0
        elif side == "R":
            x, y, angle = half_w + 5.08, (count - 1 - 2 * idx) * 1.27, 180
        elif side == "T":
            x, y, angle = (idx - count // 2) * 2.54, half_h + 5.08, 270
        else:
            x, y, angle = (idx - count // 2) * 2.54, -half_h - 5.08, 90
        shape = "inverted" if pname.endswith("_N") else "line"
        return (
            f'      (pin {ptype} {shape} (at {x:.3f} {y:.3f} {angle}) (length 5.08) '
            f'(name "{q(pname)}" (effects (font (size 1.016 1.016)))) '
            f'(number "{q(number)}" (effects (font (size 1.016 1.016)))))'
        )

    for side in "LRTB":
        for idx, pin in enumerate(sides[side]):
            out.append(pin_line(pin, idx, len(sides[side])))
    out += ["    )", "  )"]
    return "\n".join(out)
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

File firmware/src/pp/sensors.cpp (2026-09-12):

#include "pp/sensors.h"

#include <cmath>

namespace pp {

// ---------------- SHT40 ----------------

uint8_t Sht40::crc8(const uint8_t* data, size_t n) {
    // Sensirion SHT4x DS v6.4 §4.4 Table 7: poly 0x31, init 0xFF,
    // no reflection, final XOR 0x00.
    uint8_t crc = 0xFF;
    for (size_t i = 0; i < n; i++) {
        crc ^= data[i];
        for (int bit = 0; bit < 8; bit++) {
            crc = (crc & 0x80) ? (uint8_t)((crc << 1) ^ 0x31)
                               : (uint8_t)(crc << 1);
        }
    }
    return crc;
}

bool Sht40::read(float* temperature_c, float* humidity_rh) {
    const uint8_t cmd = 0xFD;  // high-repeatability T&RH (DS §4.5)
    uint8_t rx[6] = {0};
    // Clock stretching covers the ~8.2 ms conversion on normal I2C masters;
    // Wire has a bus timeout so a stuck bus fails the transfer (R-04).
    if (!i2c_->write_read(kAddr, &cmd, 1, rx, 6)) return false;
    if (crc8(rx, 2) != rx[2] || crc8(rx + 3, 2) != rx[5]) return false;
    const uint32_t st = (uint32_t(rx[0]) << 8) | rx[1];
    const uint32_t srh = (uint32_t(rx[3]) << 8) | rx[4];
    // DS §4.6 eq (2) and eq (1); RH cropped to physical 0..100 %RH range.
    *temperature_c = -45.0f + 175.0f * float(st) / 65535.0f;
    float rh = -6.0f + 125.0f * float(srh) / 65535.0f;
    if (rh < 0.0f) rh = 0.0f;
    if (rh > 100.0f) rh = 100.0f;
    *humidity_rh = rh;
    return true;
}

// ---------------- VEML7700 ----------------

bool Veml7700::write_reg(uint8_t reg, uint16_t value) {
    // Datasheet "COMMAND REGISTER FORMAT": write command code, then LSB, MSB.
    const uint8_t tx[3] = {reg, uint8_t(value & 0xFF), uint8_t(value >> 8)};
    return i2c_->write_read(kAddr, tx, 3, nullptr, 0);
}

bool Veml7700::read_reg(uint8_t reg, uint16_t* value) {
    const uint8_t ptr = reg;  // CRUD mode: pointer write, then read 16-bit LE
    uint8_t rx[2] = {0, 0};
    if (!i2c_->write_read(kAddr, &ptr, 1, rx, 2)) return false;
    *value = uint16_t(rx[0]) | (uint16_t(rx[1]) << 8);
    return true;
}

bool Veml7700::begin() {
    // ALS_CONF_0 (0x00): gain x1 (00b), IT 100 ms (0000b), persistence 1,
    // interrupt disabled, ALS_SD=0 (power on). Datasheet default is shut
    // down ("command code 0 default value is 01"), so this write is required.
    return write_reg(0x00, 0x0000);
}

float Veml7700::lux_from_counts(uint16_t counts, uint8_t gain_bits,
                                uint16_t it_ms) {
    // Vishay AN 84323 (Rev 06-Mar-2025) resolution table:
    // scale = 0.0042 lx/count at gain x2, IT 800 ms; halves per gain step,
    // scales with integration time.
    float gain_mult;
    switch (gain_bits) {
        case 0b00: gain_mult = 1.0f; break;
        case 0b01: gain_mult = 2.0f; break;
        case 0b10: gain_mult = 0.125f; break;
        default: gain_mult = 0.25f; break;  // 0b11
    }
    if (it_ms == 0) it_ms = 100;
    float scale = 0.0042f * (2.0f / gain_mult) * (800.0f / float(it_ms));
    float lux = float(counts) * scale;
    // AN 84323 linearity correction for >1000 lx (worked example verified
    // in unit tests: 5581 counts gain x1/4 IT 100 ms -> 1658 lx corrected).
    if (lux > 1000.0f) {
        const double l = lux;
        lux = float(6.0135e-13 * l * l * l * l - 9.3924e-9 * l * l * l +
                    8.1488e-5 * l * l + 1.0023 * l);
    }
    return lux;
}

bool Veml7700::read_lux(float* lux) {
    uint16_t als = 0;
    if (!read_reg(0x04, &als)) return false;  // ALS result register
    // This firmware always configures gain x1 / IT 100 ms (begin()).
    *lux = lux_from_counts(als, 0b00, 100);
    return true;
}

// ---------------- ADS1115 ----------------

bool Ads1115::write_reg(uint8_t reg, uint16_t value) {
    // Big-endian 16-bit register access via pointer byte (DS §8.1.1).
    const uint8_t tx[3] = {reg, uint8_t(value >> 8), uint8_t(value & 0xFF)};
    return i2c_->write_read(kAddr, tx, 3, nullptr, 0);
}

bool Ads1115::read_reg(uint8_t reg, uint16_t* value) {
    const uint8_t ptr = reg;
    uint8_t rx[2] = {0, 0};
    if (!i2c_->write_read(kAddr, &ptr, 1, rx, 2)) return false;
    *value = (uint16_t(rx[0]) << 8) | rx[1];
    return true;
}
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

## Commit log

2026-09-05 docs: scaffold pot-pulse hardware project, planning docs, and preliminary BOM
    [preliminary-bom.csv]
2026-09-06 docs(hardware): select datasheet-backed components (#10)
    [component-selection.csv, preliminary-bom.csv]
2026-09-07 feat(hardware): add first-pass KiCad schematic (#11)
    Add the editable KiCad 9 project, datasheet-backed project symbols,
    USB/power/sensor/debug connectivity, named test access, native ERC and
    reproducible static validation for issue #3.
    [pot-pulse.kicad_sch]
2026-09-08 feat(bom): add schematic-owned BOM pipeline (#12)
    Export grouped board parts from KiCad symbol properties, track
    non-schematic procurement items, and validate reproducibility and
    field completeness with explicit dated-price evidence.
    [bom.csv, non-schematic-items.csv, pot-pulse.kicad_sch]
2026-09-12 feat(hardware): add first-pass PCB layout with DRC and testability evidence (#13)
    Closes #5. Adds editable hardware/kicad/pot-pulse.kicad_pcb generated via
    the pcbnew Python API (build_pcb.py) from the issue #3 schematic netlist:
    - 70x50 mm 4-layer board: F.Cu/In1.GND/In2.+3V3/B.Cu; USB-C left, zone
    connectors right, ESP32-C3 antenna + RF rule-area keepout at bottom edge,
    3x M3 mounting holes; courtyard- and edge-checked placement table.
    - Net classes: Power 0.5mm, USB 0.15mm (GCT staggered fanout), Analog.
    - Routing via FreeRouter (headless, 2-layer-constrained DSN) with per-pass
    kicad-cli DRC adjudication persisted under reports/routing/.
    - Final state: 0 clearance/short/keepout/cou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
    [pass1-2l.dsn, pass1.dsn, pass2-2l.dsn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]
2026-09-12 feat(firmware): ESP32-C3 MVP with pinned build, calibration, and local API tests (#14)
    Implements issue #6 against the docs/architecture.md + docs/protocol.md
    baseline:
    - Portable C++17 core (firmware/src/pp/) compiled in both targets:
    datasheet-cited drivers (SHT4x DS v6.4 CRC-8/0xFD/eq1-2; VEML7700 Rev
    1.8 + AN 84323 lux table + >1000 lx correction; ADS1115 TI 2024
    config/pointer/single-shot), per-zone dry/wet calibration (polarity-
    agnostic), bounded 2048-sample ring (R-07), validated KV-persisted
    config + nonce-based pairing with out-of-band USB confirmation (R-06).
    - Device layer (src/main.cpp): ESP32-C3 WebServer serving every
    /api/v1 resource from protocol.md (status/hist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
    [main.cpp]
2026-09-13 feat(app): local-first companion app for setup, trends, export, and accessibility (#15)
    Implements issue #7 against the frozen /api/v1 contract (docs/protocol.md,
    firmware issue #6). Vanilla TypeScript + Vite (pinned), no framework.
    - Typed protocol client: status/history/pair/calibration/config/export/
    backup/restore/history-delete/reset; X-PotPulse-Token auth; typed mapping
    of 401/409/422/428; forward-compatible with unknown additive fields.
    - Client-side validation mirroring firmware bounds (device re-validates).
    - Setup flow: connect, nonce pairing hand-off to USB serial confirmation,
    zone naming, sampling interval, dry/wet calibration.
    - Dashboard: live status with quality states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
2026-09-14 docs(hardware): publish bring-up/assembly handoff and release evidence (#16)
    [bom.csv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]
